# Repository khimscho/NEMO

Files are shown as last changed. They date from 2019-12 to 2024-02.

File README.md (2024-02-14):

# Low-cost Data Logger System

## Purpose

This repository contains the hardware designs, firmware source code, and supporting applications and libraries for a low-cost data logger aimed at the NMEA ([National Marine Electronics Association](https://www.nmea.org)) 0183 and 2000 protocols, as used in many marine electronics systems.  The goal is to provide a minimally-functional system to record the data appearing on NMEA0183 and NMEA2000 busses on board ships, which can be used to provide volunteer depth observations (and many other things) to assist in mapping the oceans.

## Why Have Another Logger?

There is a robust infrastructure of data loggers for both NMEA0183 and NMEA2000 busses, but they are often intended for different purposes (e.g., voyage data recorders, WiFi gateways, etc.), and they are typically order US$250 [2020] or more.  This project came out of efforts within the [Seabed 2030](https://seabed2030.gebco.net) project to map the world ocean completely by 2030, where large-scale mapping is required if the goals of the programme are to be met.  Consequently, while volunteer data is a part of the solution, it has to be something that can be scaled to very large data collections.  Since it has proven hard to sustain open data collection of this type (most of the sustained efforts have been closed, with data only going back to the collectors, and not to open databases), we believe that the only viable financial model for this purpose is to give the hardware away for free, rather than attempting to sell it for profit.  That is, the hardware is free to the data collector, who is asked just to host the hardware on their ship.  Because of this model, we need the hardware to be as low-cost as possible.

This project is therefore aimed at designing as simple, and low-cost, a logger as possible, so that as many as possible can be built and distributed to assist in mapping the oceans.  The target price is order US$30 [2020] for one interface (either NMEA0183 or NMEA2000), or US$40 [2020] for both interfaces.

At the same time, we recognise that getting data from the loggers into the national and international databases can be difficult, and ask a lot of the volunteer data collectors.  The project is therefore also attempting to define a workflow for submission of data to the [International Hydrographic Office](https://iho.int)'s [Data Center for Digital Bathymetry](https://www.ngdc.noaa.gov/iho/), hosted by the [National Centers for Environmental Information](https://www.ngdc.noaa.gov) in Boulder, CO.  The goal is to have a "Trusted Node in a Box", so that anyone wanting to support collection of data of this kind has everything they need to support a very basic data flowpath direct from the loggers through the cloud to DCDB.  (Developers are then free to add on anything else they need.)

## What Does the Logger Do?

The logger's functionality is deliberately constrained.  During normal operations, the logger monitors the NMEA0183 and/or NMEA2000 busses to which it is attached, and records any valid data packet received to local storage.  Timestamps are provided through the elapsed time counter on the microcontroller used, and although a pseudo-time is computed from NMEA2000 data packets if they are available, there is no expectation that timestamps will be assigned until the data is uploaded for processing.

The logger provides an always-on Bluetooth Low Energy service that acts as a software UART.  Client software can connect to this service and pass ASCII commands to the logger to control logging, determine the files that have been logged and their sizes, manage log files, set non-volatile parameters for the system, and so on.  Critically, the BLE service can also be used to start and stop the logger's WiFi service, which is used to give higher-speed transfer of data (although it also responds to all of the same commands).  This avoids having another WiFi network on board the ship if it is not required.

After upload to a mobile collection device (e.g., a cell-phone or tablet), the data is then sent to Amazon Web Services at the first stable communications connection of the mobile device, at which point it is processed, reformatted, packaged, and transmitted to DCDB for archive.

## Concept of Operations

This logger is designed for supported, focussed, data collections.  In this mode, loggers would be provided by an organisation in a specific geographic location to support data collection in a particular area.  The goal here is to provide density of observations in an area, which greatly assists in processing the data, and making useful products.  In addition to providing the loggers (and recruiting the volunteer observers), the organisation would also provide local support personnel to visit the volunteer observers, pick up the collected data (via mobile device), and make sure that the loggers were still collecting data.  Having local support also ensures that there is continued communication with the observers, which is useful in sustaining the community in the long term.

After each visit, all of the data collected (potentially from multiple observers) on the mobile device can be uploaded to any available service that implements the cloud segment of the software suite.  This could be something set up specifically for the organisation using the model provided here, or it could be a third-party that provides an equivalent.

## Licensing and Distribution

In order to provide for the widest possible use (and to avoid excuses ...) the hardware designs, firmware source, and supporting libraries are all released as Open Source under the MIT license.  The cloud segment is released under the MIT License for non-commercial use; for commercial licenses, please contact info@ccom.unh.edu.

## Where to Start
See the "Logger firmware" section below to get started with the WIBL loggers. 
See the "Data management" section below to get started using WIBL and 
`wibl-python` tools to manage and process data generated by WIBL loggers.

### Logger firmware

The source for the system is maintained in a [BitBucket repository](https://bitbucket.org/brian_r_calder/sb2030logger), which also includes a Wiki for details of the design and system development.

To build the system, you will need at least:

1. A functional Python interpreter (at least 3.6).

2. A working [Arduino](https://www.arduino.cc) development environment (at least 1.8.12), or equivalent (e.g., [embedXcode](https://embedxcode.weebly.com) 11.8.8).

3. Support for [Espressif](https://www.espressif.com) ESP32 development (with Arduino 1.8.12 this can be installed from the IDE, see [here](https://github.com/espressif/arduino-esp32) for instructions).

4. Support for NMEA2000 handling on ESP32 (you need the [base library](https://github.com/ttlappalainen/NMEA2000) and [ESP-specific](https://github.com/ttlappalainen/NMEA2000_esp32) extensions).

5. Eagle CAD (at least 9.5.2) for the hardware designs.

6. A working C++11 (at least) compiler for the software data simulator.

With these prerequisites, the recommended place to start is with the logger firmware, followed with the data parser Python, which will allow you to demonstrate that your logger is actually logging data.  For benchtop testing, the hardware data simulator can be used (with the development board) to generate simulated data on both NMEA0183 and NMEA2000 for testing logger modifications.  The WiFi Command GUI can be used to interact with a logger once WiFi is enabled, allowing you to transfer files, and decode them.

### Data management

The included [wibl-python](wibl-python/README.md) tools allow data from WIBL 
loggers to be processed into GeoJSON format and to be submitted to 
[DCDB](https://www.ngdc.noaa.gov/iho/). There is also a tool called 
[LogConvert](LogConvert) that allows data from TeamSurv and Yacht Devices
loggers to be converted to WIBL format for further processing using 
`wibl-python`.

An easy way to use both `wibl-python` and `LogConvert` is to use the official
WIBL [container images](DataManagement/containers/README.md).

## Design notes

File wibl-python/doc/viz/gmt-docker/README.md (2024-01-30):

# Build gmt image
```shell
docker build -t ccom-gmt:0.0.1-1 .
```

# Running gmt
```shell
docker run --rm --name gmt \
  --mount type=bind,src=./,dst=/gmt \
  -it ccom-gmt:0.0.1-1
```

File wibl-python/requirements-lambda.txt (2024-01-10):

setuptools
requests~=2.31.0
pynmea2~=1.18
csbschema~=1.1.1
# Pin to pre-urllib 2.0 to avoid this error:
#   Runtime.ImportModuleError: Unable to import module 'wibl.upload.cloud.aws.lambda_function':
#   urllib3 v2.0 only supports OpenSSL 1.1.1+, currently the 'ssl' module is compiled with
#   OpenSSL 1.0.2k-fips 26 Jan 2017. See: https://github.com/urllib3/urllib3/issues/2168
urllib3==1.26.18

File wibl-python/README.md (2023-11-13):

# Python code WIBL low-cost data logger system

## Installation

### Locally
```
pip install csbschema==1.1.1
pip install ./wibl-manager
pip install .
```

## Testing
To run unit tests, including detailed verification of packet data output by the data simulator, run:
```
pip install -r requirements-build.txt
pytest -n 4 --cov=wibl --cov-branch --cov-report=xml --junitxml=test-results.xml tests/unit/*.py
```

To run integration tests exercising much of the functionality of the `wibl` command line tool 
(except for file upload to S3 and submission DCDB):
```
bash ./tests/integration/test_wibl.bash
```

## Usage
```
]$ wibl --help
usage: wibl <command> [<arguments>]

    Commands include:
        datasim     Generate test data using Python-native data simulator.
        editwibl    Edit WIBL logger files, e.g., add platform metadata.
        uploadwibl  Upload WIBL logger files to an S3 bucket.
        parsewibl   Read and report contents of a WIBL file.
        dcdbupload  Upload a GeoJSON file to DCDB direct.

Python tools for WIBL low-cost data logger system

positional arguments:
  command     Subcommand to run

optional arguments:
  -h, --help  show this help message and exit
  --version   print version and exit

```

### Run WIBL data simulator
Run data simulator to generate test data and store it in a binary WIBL file:
```
$ wibl datasim -f test.bin -d 360 -s
```

For more information on simulator, use the `-h` option:
```
$ wibl datasim -h
usage: wibl datasim [-h] [-f FILENAME] [-d DURATION] [-s] [-b] [--use_buffer_constructor]
                    [--duplicate_depth_prob DUPLICATE_DEPTH_PROB] [-v]

Command line user interface for the NMEA data simulator.

options:
  -h, --help            show this help message and exit
  -f FILENAME, --filename FILENAME
                        Simulated data output filename
  -d DURATION, --duration DURATION
                        Duration (seconds) of the simulated data
  -s, --emit_serial     Write NMEA0183 simulated strings
  -b, --emit_binary     Write NMEA2000 simulated data packets
  --use_buffer_constructor
                        Use buffer constructor, rather than data constructor, for data packets. If not specified, data
                        constructor will be used.
  --duplicate_depth_prob DUPLICATE_DEPTH_PROB
                        Probability of generating duplicate depth values. Default: 0.0
  -v, --verbose         Produce verbose output.
```

### Edit WIBL file
Add platform metadata to existing binary WIBL file (e.g., from data simulator or from a real datalogger):
```
$ wibl editwibl -m sensor-inject.json test.bin test-inject.bin
```

### Process WIBL file into GeoJSON
Convert a binary WIBL file into GeoJSON:
```
$ wibl procwibl -c tests/fixtures/configure.local.json test-inject.bin test-inject.geojson
```

> Note: It is necessary to supply a configuration JSON file with the `local` attribute
> set to `true`, such as `tests/fixtures/configure.local.json`, because `procwibl` uses
> the same code as the conversion processing lambda code run in the cloud.

### Upload WIBL files into AWS S3 Buckets for processing
Instead of using the mobile app (and for testing), WIBL binary files can be uploaded into a given S3 bucket to trigger processing.  If the file is being uploaded into the staging bucket (i.e., to test transfer to DCDB), a '.json' extension must be added (``-j|--json``), and the SourceID tag must be set (``-s|--source``) so that the submission Lambda can find this information.
```
$ wibl uploadwibl -h
usage: wibl uploadwibl [-h] [-b BUCKET] [-j] [-s SOURCE] input

Upload WIBL logger files to an S3 bucket (in a limited capacity)

positional arguments:
  input                 WIBL format input file

options:
  -h, --help            show this help message and exit
  -b BUCKET, --bucket BUCKET
                        Set the upload bucket name (string)
  -j, --json            Add .json extension to UUID for upload key
  -s SOURCE, --source SOURCE
                        Set SourceID tag for the S3 object (string)
```

### Parse WIBL binary files
Raw WIBL binary files can be read and transcribed in ASCII format for debug.  Statistics on which NMEA2000 talkers, and which packets, are observed can be dumped at the end of the read (``-s|--stats``).
```
$ wibl parsewibl -h
usage: wibl parsewibl [-h] [-s] input

Parse WIBL logger files locally and report contents.

positional arguments:
  input        Specify the file to parse

options:
  -h, --help   show this help message and exit
  -s, --stats  Provide summary statistics on packets seen
```

### Uploading GeoJSON files to DCDB directly
Instead of using the cloud-based submission process (and for debugging), pre-formatted GeoJSON files can be uploaded directly to DCDB for archival.  Note that the file containing the provider authorisation token (provided by DCDB for each Trusted Node) has to be set on the command line (``-a|--auth``), although the rest of the information (provider ID, upload point) can be specified through the JSON configuration file (``-c|--config``); the provider ID (specified by DCDB for each Trusted Node) can be over-ridden on the command line (``-p|--provider``).  The source ID is read from the GeoJSON file, unless it is set on the command line (``-s|--source``).

```
wibl dcdbupload -h
usage: wibl dcdbupload [-h] [-s SOURCEID] [-p PROVIDER] [-a AUTH] [-c CONFIG] input

Upload GeoJSON files to DCDB for archival.

positional arguments:
  input                 GeoJSON file to upload to DCDB

optional arguments:
  -h, --help            show this help message and exit
  -s SOURCEID, --sourceid SOURCEID
                        Set SourceID as in the GeoJSON metadata.
  -p PROVIDER, --provider PROVIDER
                        Provider ID as generated by DCDB
  -a AUTH, --auth AUTH  File containing the Provider authorisation token generated by DCDB
  -c CONFIG, --config CONFIG
                        Specify configuration file for installation
```

Configuration files suitable for uploading to both the test and production DCDB endpoints are available in the
[examples](examples) directory; For test uploads, use [configure-submission-test.json](examples/configure-submission-test.json),
and for production uploads use [configure-submission.json](examples/configure-submission.json).

## Packaging and Deploying Processing and Submission Code
Packaging up the software for the cloud segment, and deploying it, can be a little involved due to security concerns with the various cloud providers.  Detailed setup instructions, and automation scripts, are provided as described below.

### AWS
There are a number of steps required to set up the AWS Lambdas, the S3 buckets, and associated triggers and permissions in order to make processing work in the cloud.  The steps are covered in detail in the [Setup Instructions](scripts/cloud/AWS/README.md), and a corresponding set of scripts are available in the [scripts](scripts/cloud/AWS) directory in the repository.  These scripts should *mostly* work, but will likely need some modification for a local configuration before being fully executable.  Consider the `configuration-parameters.sh` file first for this.

## Configuration for Local Use
The ``wibl`` tool can be installed locally as above, but needs a configuration JSON file for some of the sub-commands (e.g., to send data to DCDB) rather than using environment variables as with the cloud-based processing.  Scripts in `wibl-python/scripts/desktop` will generate the `configure/json` required (configure `configuration-parameters.sh` and then run `configure-desktop.sh`).

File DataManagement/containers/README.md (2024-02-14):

# Base container images for running WIBL in Docker
This page describes how to use WIBL base container imagers for running WIBL
in Docker or other container runtime environments.

There are currently two tags for the WIBL container image: `1.0.3-amazonlinux`
and `1.0.3`, which at present reference the same image. For more information
see [here](https://github.com/CCOMJHC/WIBL/pkgs/container/wibl). In the 
future these may be separated into distinct images for those not using
Amazon Linux.

The WIBL container image contains installed and runnable versions of both 
[wibl-python](../../wibl-python/README.md) and [LogConvert](../../LogConvert). 
For more information about how these tools and setup and installed, see
the [Dockerfile](cloud/AWS/Dockerfile).

To see how the WIBL container image was built, see [BUILDING.md](BUILDING.md).

## Use directly using `docker run`
To run a `wibl-python` command within the container while reading and
writing data from a directory on your host computer, do the following:
```shell
$ docker run -v ./:/var/wibl -ti ghcr.io/ccomjhc/wibl:1.0.3 'wibl datasim -f test.bin -d 360 -b'
...
INFO:wibl.command.datasim:Step to time: 359000000
INFO:wibl.command.datasim:Step to time: 359157800
INFO:wibl.command.datasim:Step to time: 360000000
INFO:wibl.command.datasim:Total iterations: 600
$ docker run -v ./:/var/wibl -ti ghcr.io/ccomjhc/wibl:1.0.3 'wibl editwibl -m sensor-inject.json test.bin test-inject.bin'
...
```

where:
 - `-v ./:/var/wibl` mounts the current working directory from the host to `/var/wibl` in the container.
 - `'wibl datasim -f test.bin -d 360 -b'` is the `wibl-python` command to run in the container

> Note: the entire command to be run in the container must be enclosed in quotes

Since it can be error-prone to specify the full `docker run` command each
time you run a `wibl-python` command, it can be easier to open a shell
in the `wibl-base` container, then run multiple `wibl` commands:
```shell
$ docker run -v ./:/var/wibl -ti ghcr.io/ccomjhc/wibl:1.0.3
bash-5.2# wibl datasim -f test.bin -d 360 -b
...
INFO:wibl.command.datasim:Step to time: 359000000
INFO:wibl.command.datasim:Step to time: 359467302
INFO:wibl.command.datasim:Step to time: 360000000
INFO:wibl.command.datasim:Total iterations: 603
bash-5.2# wibl editwibl -m sensor-inject.json test.bin test-inject.bin 
...
bash-5.2# exit
exit
```

## Use in your own `Dockerfile`
To build your own image based off of the WIBL image, make a `Dockerfile` that
begins with the following:
```Dockerfile
FROM ghcr.io/ccomjhc/wibl:1.0.3
...
```

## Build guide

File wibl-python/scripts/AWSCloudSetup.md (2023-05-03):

# Packaging and deploying AWS lambdas for DCDB processing
There are a number of steps required to set up the AWS Lambdas, the S3 buckets, and associated triggers and permissions in order to make processing work in the cloud.  The steps are covered in detail below, and a corresponding set of scripts are available in the `wibl-python/AWS-setup` directory in the repository.  These scripts should *mostly* work, but will likely need some modficiation for a local configuration before being fully executable.  Consider the `configuration-parameters.sh` file first for this.

## Creating S3 Buckets
The cloud processing segment uses two AWS S3 buckets to receive the incoming data (`INCOMING_BUCKET`) and to stage processed data (`STAGING_BUCKET`) for further analysis, or before they're sent to DCDB for archive.  Creating these from the CLI is relatively straightforward:

```bash
aws s3api create-bucket \
    --bucket INCOMING_BUCKET \
    --region REGION \
    --create-bucket-configuration LocationConstraint=REGION
aws s3api create-bucket \
    --bucket STAGING_BUCKET \
    --region REGION \
    --create-bucket-configuration LocationConstraint=REGION
```

where `INCOMING_BUCKET` and `STAGING_BUCKET` are the short names for the buckets (i.e., not the full ARN), and `REGION` is the AWS region.  Since S3 buckets are global objects, you do not need to specifically set the `REGION`, but doing so can be advantageous since the data will stay within the same facility as the Lambdas, which can improve performance.  If you do not specify the region, us-east-1 (Virginia) is used.  Specifying the `create-bucket-configuration` is only required if you do specify the `REGION`.

## Create IAM roles for WIBL lambdas
First, create an IAM role for each lambda (e.g., processing and submission). We'll do this using the AWS CLI rather
than the AWS web console since this enables us to automate lambda configuration. Also, the CLI tends to change less
often than the web console user interface, so these instructions should last much longer without updating.

First create the following trust policy JSON file:
```bash
$ cat > trust-policy.json <<-HERE
{
 "Version": "2012-10-17",
  "Statement": [
    {
      "Effect": "Allow",
      "Principal": {
        "Service": ["lambda.amazonaws.com"]
      },
      "Action": "sts:AssumeRole"
    }
  ]
}
HERE
```
Then create the IAM role for the processing lambda:
```bash
$ aws iam create-role \
  --role-name wibl-processing-lambda \
  --assume-role-policy-document file://trust-policy.json
```

Next, create the IAM role for the submission lambda:
```bash
$ aws iam create-role \
  --role-name wibl-submission-lambda \
  --assume-role-policy-document file://trust-policy.json
```

> Make a copy of the role ARNs returned to you after running these commands. We'll need them to create the lambdas below.

Attach the following policy to allow Lambda to write logs in CloudWatch, processing lambda:
```bash
$ aws iam attach-role-policy \
  --role-name wibl-processing-lambda \
  --policy-arn arn:aws:iam::aws:policy/service-role/AWSLambdaBasicExecutionRole
```

also for submission lambda:
```bash
$ aws iam attach-role-policy \
  --role-name wibl-submission-lambda \
  --policy-arn arn:aws:iam::aws:policy/service-role/AWSLambdaBasicExecutionRole
```

> Note: it takes a little while for the roles to propagate out to the rest of the AWS infrastructure, so if you
> attempt to use the roles to create Lambdas before they've finished, you'll get odd errors.  Something on the
> order to 5-10 s appears to work, but this could vary depending on the region that you're in.

## Package lambdas as zipfile
> Note: the following is based on [AWS lambda deployment instructions](https://docs.aws.amazon.com/lambda/latest/dg/python-package.html#python-package-create-package-with-dependency)

Since all WIBL AWS lambdas are part of the same Python package called `wibl`, we'll only need to create a single
package. We can specify different lambda handler functions when creating the individual lambdas below.

First (and optionally), run a shell within the Amazon Linux Python 3.8 lambda runtime:
```
$ docker run \
  --mount type=bind,source="$(pwd)/.",target=/build \
  -it --entrypoint /bin/bash \
  public.ecr.aws/lambda/python:3.8-x86_64
```

The reason you might want to package lambdas within Amazon Linux Python 3.8 lambda runtime is that it should be nearly
identical to the environment where the lambda will run. This way, you can reduce the risk of introducing any platform-
or architecture-specific dependencies. That said, since we are using AWS layers to configure some of the dependencies
for our lambdas (e.g., including platform- and architecture-specific dependencies such as numpy), and since the
dependencies we *are* bundlying in our lambda zipfile (as specified by
[requirements-lambda.txt](requirements-lambda.txt)) *should* be pure Python, it *should* be okay to create this
package on either non-Amazon versions of Linux, or under recent versions of macOS. However, it is probably a good idea
to use Amazon Linux Python 3.8 lambda runtime to package these lambdas.

> It should be possible to use the ARM64 architecture to package and deploy the Lambdas, but there are limitations
> to the support facilities in the currently available Lambda runtimes, particularly with respect to Python versions
> and SciPy installed versions.  This can cause the Lambda to abort before booting when triggered.

> Similarly, it should be possible to use more recent Python runtimes, but they often don't have good support for the
> SciPy layer that's required for the WIBL code.  This may change over time; the WIBL code is typically tested with
> the most recent version of Python.

Second, install WIBL and its dependencies into a target directory called `package` located in the current directory:
```
$ cd /build
$ pip install --target ./package -r requirements-lambda.txt
$ pip install --target ./package ./wibl-manager
$ pip install --target ./package --no-deps .
```

> Note: if building in Amazon Linux Python 3.8 lambda runtime, make sure to run these in the shell you started in
> Docker above rather than in a shell on your host OS.  You can do this by hand, or by sending the commands into a file, and then piping it into the docker command (remove the ``-t`` option if you do this).

> Note: we break out the install into two steps so that we package *only* the subset of `wibl` dependencies that will
> not be provided by AWS lambda layers used when we create the lambda below.

Next, make a zipfile of the `package` directory:
```
$ pushd .
$ cd package
$ zip -r ../wibl-package.zip .
$ popd
```

> Note: if building in Amazon Linux Python 3.8 lambda runtime, you'll have to run this from your host since `zip` is not
> installed by default.

## Create the processing lambda
```
$ aws lambda create-function \
  --function-name wibl-processing \
  --role arn:aws:iam::ACCOUNT_NUMBER:role/wibl-processing-lambda \
  --runtime python3.8 --timeout 30 --memory-size 2048 \
  --handler wibl.processing.cloud.aws.lambda_function.lambda_handler \
  --zip-file fileb://wibl-package.zip \
  --architectures x86_64 \
  --layers LAYER1 ... LAYERN \
  --environment "Variables={PROVIDER_ID=MY_PROVIDER_ID,STAGING_BUCKET=MY_STAGING_BUCKET,UPLOAD_POINT=https://www.ngdc.noaa.gov/ingest-external/upload/csb/geojson/}"
```

where `ACCOUNT_NUMBER` is your AWS account number, and where `LAYER1 ... LAYERN` are replaced by the names of the AWS lambda layers we would like to deploy this lambda on top of (to avoid repackaging dependencies).  See the example configuration file for definitions of the environment variables.

> Note: by default, the lambda will use the configuration file installed as part of the `wibl` Python package. You can
> find this default file in [here](wibl/defaults/processing/cloud/aws/configure.json). If you want to use another file,
> make sure to add it to the `package` directory created above and set an environment variable named `WIBL_CONFIG_FILE`
> (value is the path within the package to the desired configuration file) when creating the lambda function.

> Note: if you want to use ARM64 instead of x86_64 architecture, change `--architectures x86_64` to
> `--architectures arm64`.

> The `timeout` and `memory-size` settings may have to be adjusted for your implementation; these defaults work
> reasonably for the default code-base.

> Note: the layer name is the full ARN for the layer required.  You will need at least the SciPy layer for a
> default build of the code; this is likely
> arn:aws:lambda:us-east-2:259788987135:layer:AWSLambda-Python38-SciPy1x:107 (or the equivalent for your AWS region).

## Configure the Processing Lambda to Trigger from S3
To have the processing lambda triggered by the upload of a file into an S3 bucket, you need to configure the lambda to be triggerable, configure the bucket to generate notifications (and send them to the lambda), and then configure the lambda to allow for access to the S3 bucket.  In order:

```
$ aws lambda add-permission \
  --function-name wibl-processing \
  --action lambda:InvokeFunction \
  --statement-id s3invoke \
  --principal s3.amazonaws.com \
  --source-arn arn:aws:s3:::INCOMING_BUCKET \
  --source-account ACCOUNT_NUMBER
```
where `INCOMING_BUCKET` is the name of the S3 bucket that you'll upload data into from the outside world, and `ACCOUNT_NUMBER` is the AWS account number for your installation.

> Note: Some services can invoke functions in other accounts. If you specify a source
> ARN that has your account ID in it, that isn't an issue. For Amazon S3, however, the
> source is a bucket whose ARN doesn't have an account ID in it. It's possible that you
> could delete the bucket and another account could create a bucket with the same name.
> Using the source-account option with your account ID ensures that only resources in
> your account can invoke the function.

> Note: Once the permissions are added to the Lambda, there's a propagation time for the Lambda to complete
> setup, and then propagate this out to the rest of the AWS infrastructure.  If you attempt to target the
> Lambda (e.g., to do the next stage of adding the trigger) without waiting for this to happen, odd errors
> occur.  A delay of 5-10 s seems to be appropriate, but may depend on the region that you're in.

Generate a configuration file for the bucket to notify the lambda:
```bash
$ cat > bucket-notification-cfg.json <<-HERE
{
    "LambdaFunctionConfigurations": [
        {
            "Id": "IDENTIFIER",
            "LambdaFunctionArn": "arn:aws:lambda:REGION:ACCOUNT_NUMBER:function:wibl-processing",
            "Events": [
                "s3:ObjectCreated:Put",
                "s3:ObjectCreated:CompleteMultipartUpload"
            ]
        }
    ]
}
HERE
```
where `IDENTIFIER` is a unique identifier (e.g., a UUID), `REGION` is your AWS region, and `ACCOUNT_NUMBER` is as above.  You can obtain the ARN for your bucket directly from the AWS console if necessary.  Then apply the notification to the bucket:

```bash
$ aws s3api put-bucket-notification-configuration \
  --bucket INCOMING_BUCKET \
  --notification-configuration file://bucket-notification-cfg.json
```
where `INCOMING_BUCKET` is the short form name of the bucket you're using for incoming files, as above.

Finally, generate a configuration file to allow the lambda access to the S3 bucket:
```bash
$ cat > lambda-s3-access.json <<-HERE
{
    "Version": "2012-10-17",
    "Statement": [
        {
            "Sid": "LambdaAllowS3Access",
            "Effect": "Allow",
            "Action": [
                "s3:*"
            ],
            "Resource": [
                "arn:aws:s3:::INCOMING_BUCKET",
                "arn:aws:s3:::INCOMING_BUCKET/*",
                "arn:aws:s3:::STAGING_BUCKET",
                "arn:aws:s3:::STAGING_BUCKET/*"
            ]
        }
    ]
}
HERE
```
and apply it to the lambda:
```bash
$ aws iam put-role-policy \
  --role-name wibl-processing-lambda \
  --policy-name lambda-s3-access \
  --policy-document file://lambda-s3-access.json
```
and then convince yourself that it has been applied:
```bash
$ aws iam list-role-policies --role-name wibl-processing-lambda
```
which should report something like:
```
{
    "PolicyNames": [
        "lambda-s3-access"
    ]
}
```

At this stage, submitting a WIBL file to the `INCOMING_BUCKET` should result in the file being processed and written into the `STAGING_BUCKET` that was specified in the environment variables of the WIBL package.

## Create the submission lambda
```bash
$ aws lambda create-function \
  --function-name wibl-submission \
  --role arn:aws:iam::ACCOUNT_NUMBER:role/wibl-submission-lambda \
  --runtime python3.8 --timeout 30 --memory-size 2048 \
  --handler wibl.submission.cloud.aws.lambda_function.lambda_handler \
  --zip-file fileb://wibl-package.zip \
  --architectures x86_64 \
  --environment "Variables={PROVIDER_ID=MY_PROVIDER_ID,PROVIDER_AUTH=MY_PROVIDER_AUTH_KEY,STAGING_BUCKET=MY_STAGING_BUCKET,UPLOAD_POINT=https://www.ngdc.noaa.gov/ingest-external/upload/csb/geojson/}"
```

> Note: the submission lambda takes an additional environment variable `PROVIDER_AUTH`, which is an authentication key
> used for making submissions to the HTTP service denoted by `UPLOAD_POINT`.

> Note: by default, the lambda will use the configuration file installed as part of the `wibl` Python package. You can
> find this default file in [here](wibl/defaults/submission/cloud/aws/configure.json). If you want to use another file,
> make sure to add it to the `package` directory created above and set an environment variable named `WIBL_CONFIG_FILE`
> (value is the path within the package to the desired configuration file) when creating the lambda function.

## Configure the Submission Lambda to Automatically Trigger
The process for this is essentially the same as for the processing Lambda, with some obvious modifications to match the particular buckets in use.

First, create a bucket notification so that files being added to the STAGING_BUCKET by the processing Lambda trigger the submission Lambda:
```bash
cat >bucket-notification-cfg.json <<-HERE
{
    "LambdaFunctionConfigurations": [
        {
            "Id": "${UUID}",
            "LambdaFunctionArn": "arn:aws:lambda:REGION:ACCOUNT_NUMBER:function:wibl-submission",
            "Events": [
                "s3:ObjectCreated:Put",
                "s3:ObjectCreated:CompleteMultipartUpload"
            ]
        }
    ]
}
HERE
```

and then apply it to the STAGING_BUCKET as before:
```bash
aws s3api put-bucket-notification-configuration \
	--bucket STAGING_BUCKET \
	--notification-configuration file://bucket-notification-cfg.json
```

Next, generate an access policy to allow the submission Lambda to access the STAGING_BUCKET:
```bash
cat >lambda-s3-access.json <<-HERE
{
    "Version": "2012-10-17",
    "Statement": [
        {
            "Sid": "LambdaAllowS3Access",
            "Effect": "Allow",
            "Action": [
                "s3:*"
            ],
            "Resource": [
                "arn:aws:s3:::STAGING_BUCKET",
                "arn:aws:s3:::STAGING_BUCKET/*"
            ]
        }
    ]
}
HERE
```

and then add the permissions on the submission Lambda to allow it to be invoked by S3,
```bash
aws lambda add-permission \
  --function-name wibl-submission \
	--action lambda:InvokeFunction \
	--statement-id s3invoke \
	--principal s3.amazonaws.com \
	--source-arn arn:aws:s3:::STAGING_BUCKET \
	--source-account ACCOUNT_NUMBER
```

and then add the policy for permissions,
```bash
aws iam put-role-policy \
	--role-name wibl-submission-lambda \
	--policy-name lambda-s3-access \
	--policy-document file://lambda-s3-access.json
```

> Note: The same delays between Lambda creation and adding the trigger as for the processing Lambda are required.

# Upload a New Version of a Lambda
```bash
$ aws lambda update-function-code --function-name wibl-processing \
  --zip-file fileb://wibl-package.zip
```

# Change Lambda Environment
```bash
$ aws lambda update-function-configuration \
  --function-name wibl-submission \
  --environment "Variables={PROVIDER_ID=MY_PROVIDER_ID_UPDATED,PROVIDER_AUTH=MY_PROVIDER_AUTH_KEY_UPDATED,STAGING_BUCKET=MY_STAGING_BUCKET_UPDATED,UPLOAD_POINT=https://www.ngdc.noaa.gov/ingest-external/upload/csb/geojson/}"
```

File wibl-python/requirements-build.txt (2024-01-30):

setuptools
boto3~=1.20
requests~=2.31.0
numpy~=1.20
pynmea2~=1.18
csbschema~=1.1.1
pygmt~=0.10.0
rasterio~=1.3.0
GDAL
pylint~=3.0.0
unittest-xml-reporting==3.2.0
lxml~=5.0.0
pytest~=7.4.0
pytest-cov
pytest-xdist
pytest-docker[docker-compose-v2]

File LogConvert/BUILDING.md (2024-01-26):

# Instructions for building LogConvert

## Amazon Linux 2023
Use the provided [Dockerfile](Dockerfile) as a starting point for building and running LogConvert
in Amazon Linux 2023 environments (e.g., public.ecr.aws/lambda/python:3.12).

### AMD64
```shell
$ docker buildx build --platform linux/amd64 -t wibl/logconvert:latest ./
```

### ARM64
```shell
$ docker buildx build --platform linux/arm64 -t wibl/logconvert:latest ./
```

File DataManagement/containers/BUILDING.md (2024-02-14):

# Base container images for running WIBL in Docker
This page describes how to build WIBL base container imagers for running WIBL
in Docker or other container runtime environments. The following steps
assum you are using [Docker Desktop](https://www.docker.com/products/docker-desktop/).

## Build
To build, do the following:
```shell
$ docker buildx build \
  --platform linux/amd64,linux/arm64 --builder=desktop-linux \
  -t ghcr.io/ccomjhc/wibl:1.0.3-amazonlinux -t ghcr.io/ccomjhc/wibl:1.0.3 \
  cloud/AWS
```

> Note: If you don't have a builder named `desktop-linux`, run `docker buildx ls`
> to find the name of your builder.

> Note: For now, we tag this image both as `1.0.3-amazonlinux` and 
> `1.0.3`. In the future we may plan to build a version of the that is
> not based on Amazon Linux.

To push, first store your GitHub container registry personal access token to
an environment variable named `CR_PAT`, then login:
```shell
$ echo $CR_PAT | docker login ghcr.io -u USERNAME --password-stdin
```

> For more info on pushing images, see [here](https://docs.github.com/en/packages/working-with-a-github-packages-registry/working-with-the-container-registry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)

Then push:
```shell
$ docker image push --all-tags ghcr.io/ccomjhc/wibl
```

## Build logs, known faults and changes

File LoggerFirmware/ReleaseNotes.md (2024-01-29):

# Release Notes: Logger Firmware

## Firmware 1.5.0

Firmware 1.5.0 includes the following additions:

* __Internal website__.  The logger can now host its own configuration and manipulation software, providing these to any browser as a mixture of HTML/CSS/JavaScript.  Data download is through normal browser download mechanisms by exposing the log files as a static website and providing download links as part of the website status page.  This makes the logger self-hosting.
* __Data Integrity__.  Monitoring for the latest time/position/depth on NMEA0183 and NMEA2000 inputs so that the status page on the internal website can demonstrate whether the logger is receiving data (ideal for installation, but also good for debugging while underway).
* __Auto-upload__.  If the logger is connected to a network that has internet connection, it can now be configured to automatically connect to a server to upload log files, using TLS for the connection and HTTP BasicAuth for authentication.  The upload events happen at a fixed interval, and run for a fixed duration (or until all of the files are transferred) so that the code doesn't dominate the logger's functionality while uploading.  A separate timeout parameter ensures the system doesn't halt if the server isn't available.
* __Data Monitoring__.  Ability to include algorithm requests dynamically based on the data being captured.  This resolves the issue to "no data" values in NMEA2000 inputs causing chaos in post.
* JSON output for all commands when using the WiFi interface.  This includes error messages as a JSON response with just a "messages" tag and an array of strings.
* A consistently reported firmware version in configuration and status information.
* Addition of NVM storage for an upload token (e.g., for an API key).
* "/heartbeat" API endpoint on the logger's WiFi interface now generates a full status message, rather than just the serial number of the logger.
* Console logs are now limited to a fixed (compile-time) size, but will rotate three stages (grandparent-parent-child) to preserve a little more history.
* Scales, metadata, NMEA0183 filters, and algorithm requests are now all stored as JSON data int the NVM, rather than as plain-text files.
* The status command now provides the URL at which to find each log file, as well as size, MD5 hash, ID number, and upload count.
* New command "snapshot" to generate a snapshot of the running configuration, default configuration, or file catalog as files on the SD card so that they can be downloaded to local storage on a mobile device.  The JSON response is the URL at which to find the snapshot.  The internal website implements this functionality through GUI buttons.
* New command "upload" to control auto-upload of log files.
* New command "auth" to control auto-upload authentication artifacts.
* Ability to specify more than one NMEA0183 sentence recognition string in "accept" command in a single command.

Note that this release also updates the command processor version to 1.4.0.

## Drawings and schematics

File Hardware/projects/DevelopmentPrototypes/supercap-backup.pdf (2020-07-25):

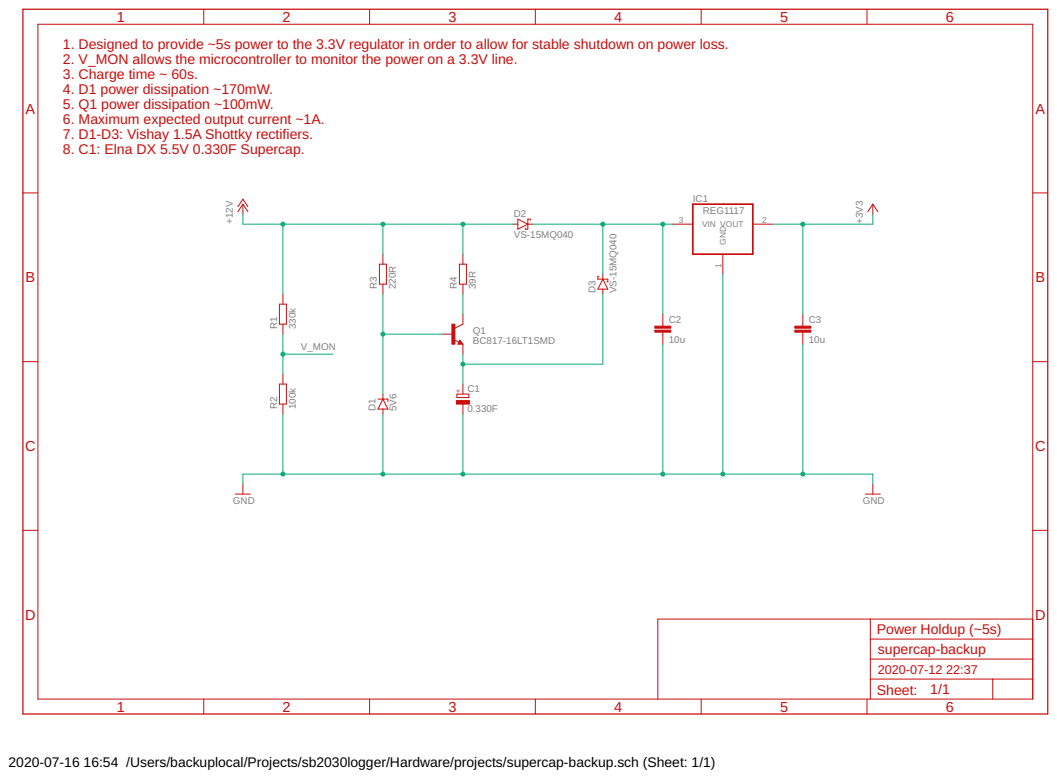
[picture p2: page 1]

1. Designed to provide ~5s power to the 3.3V regulator in order to allow for stable shutdown on power loss. 2. V_MON allows the microcontroller to monitor the power on a 3.3V line. 3. Charge time ~ 60s. 4. D1 power dissipation ~170mW. 5. Q1 power dissipation ~100mW. 6. Maximum expected output current ~1A. 7. D1-D3: Vishay 1.5A Shottky rectifiers. 8. C1: Elna DX 5.5V 0.330F Supercap.

2020-07-16 16:54 /Users/backuplocal/Projects/sb2030logger/Hardware/projects/supercap-backup.sch (Sheet: 1/1)

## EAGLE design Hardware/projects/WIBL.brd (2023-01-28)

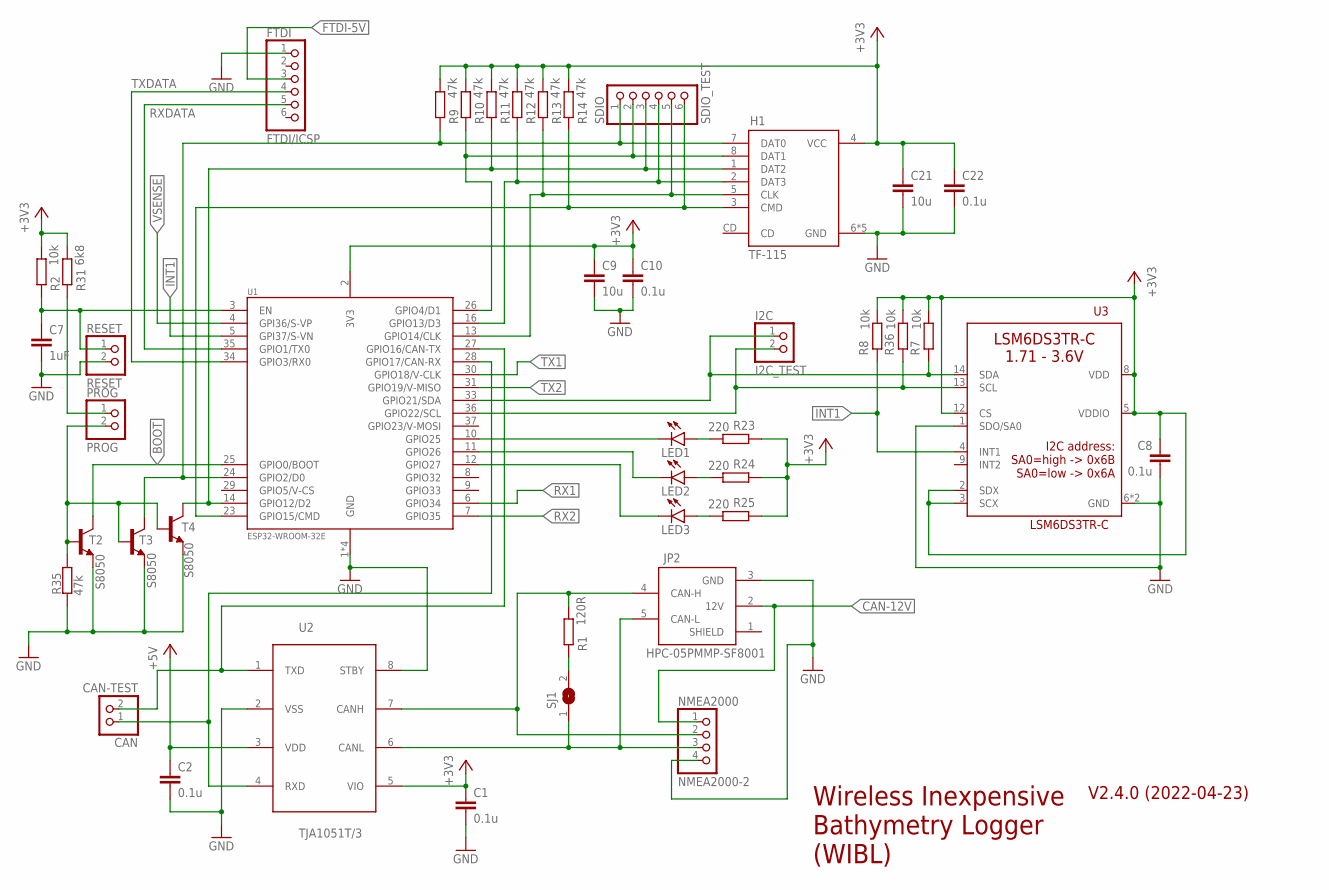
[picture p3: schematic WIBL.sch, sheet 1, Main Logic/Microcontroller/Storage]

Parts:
C1, C2, C8, C10, C22: 0.1u; C0805
C7: 1uF; C0805
C9, C21: 10u; C0805
CAN: CAN-TEST; 1X02
FTDI: FTDI/ICSP; 1X06
H1: TF-115; XUNPU-MICROSD-SOCKET
I2C: I2C_TEST; 1X02
JP2: HPC-05PMMP-SF8001; NMEA2000
LED1, LED2, LED3: LEDCHIP-LED0603; CHIP-LED0603
NMEA2000: NMEA2000-2; 1X04
PROG: PROG; 1X02
R1: 120R; R0805
R2, R7, R8, R36: 10k; R0805
R9, R10, R11, R12, R13, R14, R35: 47k; R0805
R23, R24, R25: 220; R0805
R31: 6k8; R0805
RESET: RESET; 1X02
SDIO: SDIO_TEST; 1X06
SJ1: SJ
T2, T3, T4: S8050; SOT23
U1: ESP32-WROOM-32E; ESPS32-WROOM-32E
U2: TJA1051T/3; SOIC8
U3: LSM6DS3TR-C; LGA-14-2.5X3MM

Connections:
+3V3: C1.1, C8.1, C9.1, C10.1, C21.1, C22.1, H1.4 (VCC), R2.2, R7.2, R8.2, R9.2, R10.2, R11.2, R12.2, R13.2, R14.2, R23.1, R24.1, R25.1, R31.2, R36.2, U1.2 (3V3), U2.5 (VIO), U3.2 (SDX), U3.3 (SCX), U3.5 (VDDIO), U3.8 (VDD), U3.12 (CS); also elsewhere on the board
+5V: C2.1, U2.3 (VDD); also elsewhere on the board
BOOT: T2.3 (C), U1.25 (GPIO0/BOOT); also elsewhere on the board
CAN-12V: JP2.2 (12V), NMEA2000.1; also elsewhere on the board
FTDI-5V: FTDI.3; also elsewhere on the board
GND: C1.2, C2.2, C7.2, C8.2, C9.2, C10.2, C21.2, C22.2, FTDI.1, H1.6 (GND), H1.GND1 (GND), H1.GND2 (GND), H1.GND3 (GND), H1.GND4 (GND), JP2.3 (GND), NMEA2000.4, R35.1, RESET.2, T2.2 (E), T3.2 (E), T4.2 (E), U1.1 (GND), U1.15 (GND), U1.38 (GND), U1.THERM (GND), U2.2 (VSS), U2.8 (STBY), U3.1 (SDO/SA0), U3.6 (GND), U3.7 (GND); also elsewhere on the board
INT1: R8.1, U1.5 (GPI37/S-VN), U3.4 (INT1)
unnamed: JP2.4 (CAN-H), NMEA2000.2, R1.2, U2.7 (CANH)
unnamed: JP2.5 (CAN-L), NMEA2000.3, SJ1.1, U2.6 (CANL)
unnamed: R1.1, SJ1.2
unnamed: C7.1, R2.1, RESET.1, U1.3 (EN)
unnamed: CAN.2, U1.27 (GPIO16/CAN-TX), U2.1 (TXD)
unnamed: CAN.1, U1.28 (GPIO17/CAN-RX), U2.4 (RXD)
unnamed: H1.1 (DAT2), R11.1, SDIO.3, T4.3 (C), U1.14 (GPIO12/D2)
unnamed: H1.8 (DAT1), R10.1, SDIO.2, U1.26 (GPIO4/D1)
unnamed: H1.7 (DAT0), R9.1, SDIO.1, T3.3 (C), U1.24 (GPIO2/D0)
unnamed: H1.2 (DAT3), R12.1, SDIO.4, U1.16 (GPIO13/D3)
unnamed: H1.5 (CLK), R13.1, SDIO.5, U1.13 (GPIO14/CLK)
unnamed: H1.3 (CMD), R14.1, SDIO.6, U1.23 (GPIO15/CMD)
unnamed: LED1.C, U1.10 (GPIO25)
unnamed: LED2.C, U1.11 (GPIO26)
unnamed: PROG.2, R35.2, T2.1 (B), T3.1 (B), T4.1 (B)
unnamed: LED3.C, U1.12 (GPIO27)
unnamed: LED1.A, R23.2
unnamed: LED2.A, R24.2
unnamed: PROG.1, R31.1
unnamed: LED3.A, R25.2
RX1: U1.6 (GPIO34); also elsewhere on the board
RX2: U1.7 (GPIO35); also elsewhere on the board
RXDATA: FTDI.5, U1.35 (GPIO1/TX0)
SCL: I2C.1, R7.1, U1.33 (GPIO21/SDA), U3.14 (SDA)
SDA: I2C.2, R36.1, U1.36 (GPIO22/SCL), U3.13 (SCL)
TX1: U1.30 (GPIO18/V-CLK); also elsewhere on the board
TX2: U1.31 (GPIO19/V-MISO); also elsewhere on the board
TXDATA: FTDI.4, U1.34 (GPIO3/RX0)
VSENSE: U1.4 (GPI36/S-VP); also elsewhere on the board

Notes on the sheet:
Wireless Inexpensive Bathymetry Logger (WIBL)
V2.4.0 (2022-04-23)

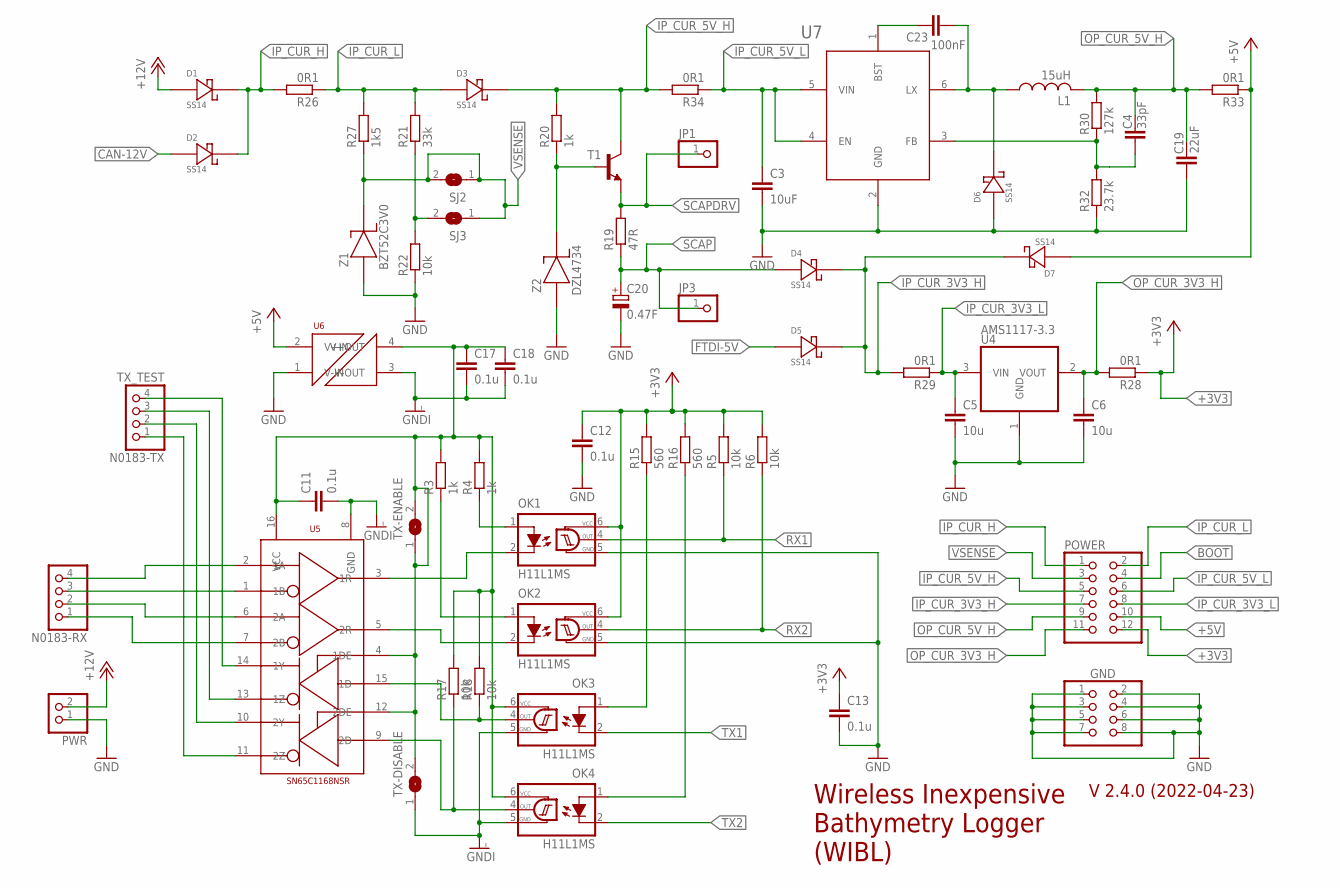
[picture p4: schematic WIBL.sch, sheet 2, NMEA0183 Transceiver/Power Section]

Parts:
C3: 10uF; C1206
C4: 33pF; C0603
C5, C6: 10u; C0805
C11, C12, C13, C17, C18: 0.1u; C0805
C19: 22uF; C0603
C20: 0.47F; P128-50
C23: 100nF; C0402
D1, D2, D3, D4, D5, D6, D7: SS14; DO-214AC
GND: PINHD-2X4; 2X04
JP1, JP3: PINHD-1X1; 1X01
L1: 15uH; MWSA0603S
N0183-RX: PINHD-1X4; 1X04
N0183-TX: TX_TEST; 1X04
OK1, OK2, OK3, OK4: H11L1MS; DIL6-SMD
POWER: PINHD-2X6; 2X06
PWR: PINHD-1X2; 1X02
R3, R4, R20: 1k; R0805
R5, R6, R17, R18, R22: 10k; R0805
R15, R16: 560; R0805
R19: 47R; R0805
R21: 33k; R0805
R26, R28, R29, R33, R34: 0R1; R0603
R27: 1k5; R0805
R30: 127k; R0603
R32: 23.7k; R0603
SJ2, SJ3: SJ
T1: BC817-16-NPN-SOT23-BEC; SOT23-BEC
TX-DISABLE: SJ
TX-ENABLE: SJ
U4: AMS1117-3.3; SOT223
U5: SN65C1168NSR; SOIC16
U6: RFM-0505S
U7: BL9352A; SOT-23-6L
Z1: BZT52C3V0; SOD123
Z2: DZL4734; SOD-123FL

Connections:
+3V3: C12.1, C13.1, OK1.6 (VCC), OK2.6 (VCC), POWER.12, R5.2, R6.2, R15.2, R16.2, R28.1; also elsewhere on the board
+5V: D7.A, POWER.10, R33.1, U6.2 (V+IN); also elsewhere on the board
+12V: D1.A, PWR.2
BOOT: POWER.4; also elsewhere on the board
CAN-12V: D2.A; also elsewhere on the board
FTDI-5V: D5.A; also elsewhere on the board
GND: C3.2, C5.2, C6.2, C12.2, C13.2, C19.1, C20.-, D6.A, GND.1, GND.2, GND.3, GND.4, GND.5, GND.6, GND.7, GND.8, OK1.5 (GND), OK2.5 (GND), PWR.1, R22.1, R32.1, U4.1 (GND), U6.1 (V-IN), U7.2 (GND), Z1.1 (A), Z2.A; also elsewhere on the board
GNDI: C11.2, C17.2, C18.2, OK3.5 (GND), OK4.5 (GND), TX-DISABLE.1, U5.8 (GND), U6.3 (V-OUT)
IP_CUR_3V3_H: D4.K, D5.K, D7.K, POWER.7, R29.2
IP_CUR_3V3_L: C5.1, POWER.8, R29.1, U4.3 (VIN)
IP_CUR_5V_H: D3.K, POWER.5, R20.2, R34.2, T1.C
IP_CUR_5V_L: C3.1, POWER.6, R34.1, U7.4 (EN), U7.5 (VIN)
IP_CUR_H: D1.K, D2.K, POWER.1, R26.2
IP_CUR_L: D3.A, POWER.2, R21.2, R26.1, R27.2
unnamed: OK1.2 (C), U5.3 (1R)
unnamed: OK2.2 (C), U5.5 (2R)
unnamed: OK1.1 (A), R4.1
unnamed: OK2.1 (A), R3.1
unnamed: N0183-RX.4, U5.2 (1A)
unnamed: N0183-RX.3, U5.1 (1B)
unnamed: N0183-RX.2, U5.6 (2A)
unnamed: N0183-RX.1, U5.7 (2B)
unnamed: C11.1, C17.1, C18.1, OK3.6 (VCC), OK4.6 (VCC), R3.2, R4.2, R17.2, R18.2, TX-DISABLE.2, TX-ENABLE.1, TX-ENABLE.2, U5.4 (1DE), U5.12 (2DE), U5.16 (VCC), U6.4 (V+OUT)
unnamed: N0183-TX.4, U5.14 (1Y)
unnamed: N0183-TX.3, U5.13 (1Z)
unnamed: N0183-TX.2, U5.10 (2Y)
unnamed: N0183-TX.1, U5.11 (2Z)
unnamed: OK3.1 (A), R15.1
unnamed: OK4.1 (A), R16.1
unnamed: OK3.4 (OUT), R18.1, U5.15 (1D)
unnamed: OK4.4 (OUT), R17.1, U5.9 (2D)
unnamed: R20.1, T1.B, Z2.K
unnamed: C23.P$1 (1), U7.1 (BST)
unnamed: C23.P$2 (2), D6.K, L1.P$1 (1), U7.6 (LX)
unnamed: R21.1, R22.2, SJ3.2
unnamed: C4.1, R30.1, R32.2, U7.3 (FB)
OP_CUR_3V3_H: C6.1, POWER.11, R28.2, U4.2 (VOUT)
OP_CUR_5V_H: C4.2, C19.2, L1.P$2 (2), POWER.9, R30.2, R33.2
RX1: OK1.4 (OUT), R5.1; also elsewhere on the board
RX2: OK2.4 (OUT), R6.1; also elsewhere on the board
SCAP: C20.+, D4.A, JP3.1, R19.1
SCAPDRV: JP1.1, R19.2, T1.E
TX1: OK3.2 (C); also elsewhere on the board
TX2: OK4.2 (C); also elsewhere on the board
VSENSE: POWER.3, R27.1, SJ2.1, SJ2.2, SJ3.1, Z1.2 (K); also elsewhere on the board

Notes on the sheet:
Wireless Inexpensive Bathymetry Logger (WIBL)
V 2.4.0 (2022-04-23)

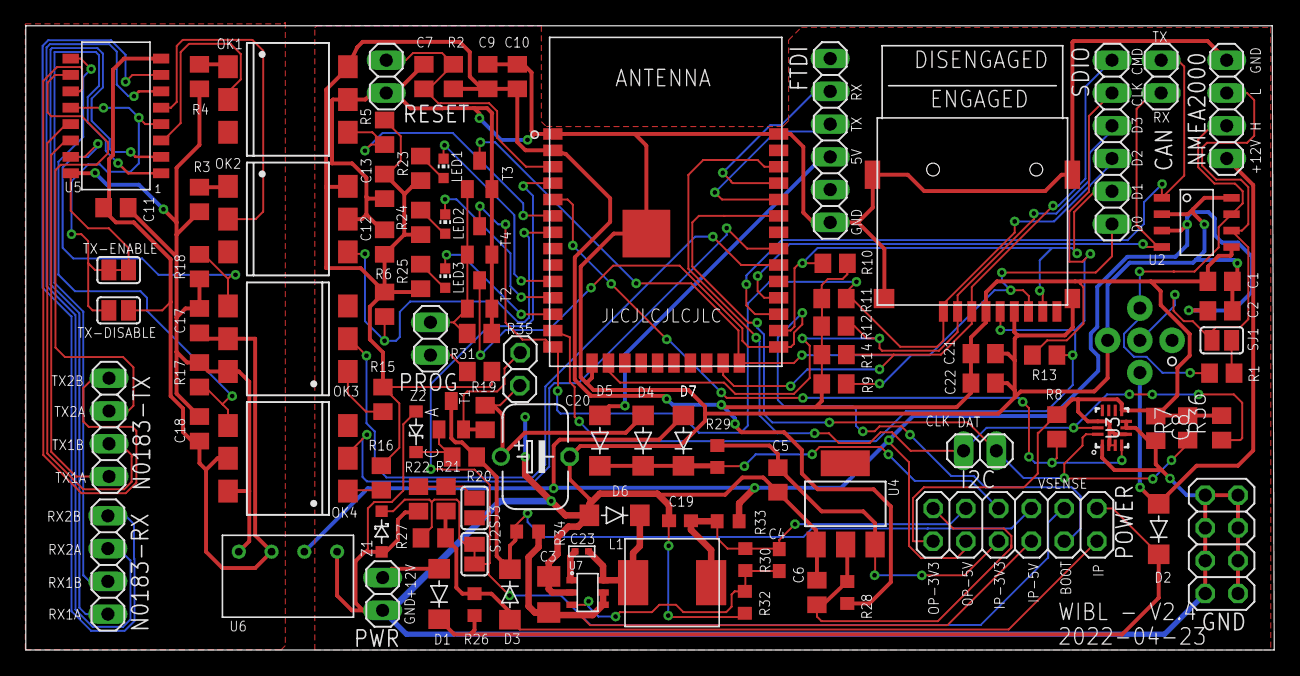
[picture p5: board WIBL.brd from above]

Board: 2 copper layers, 96.8 x 48.4 mm, 105 parts (0 on the bottom side), 70 nets.

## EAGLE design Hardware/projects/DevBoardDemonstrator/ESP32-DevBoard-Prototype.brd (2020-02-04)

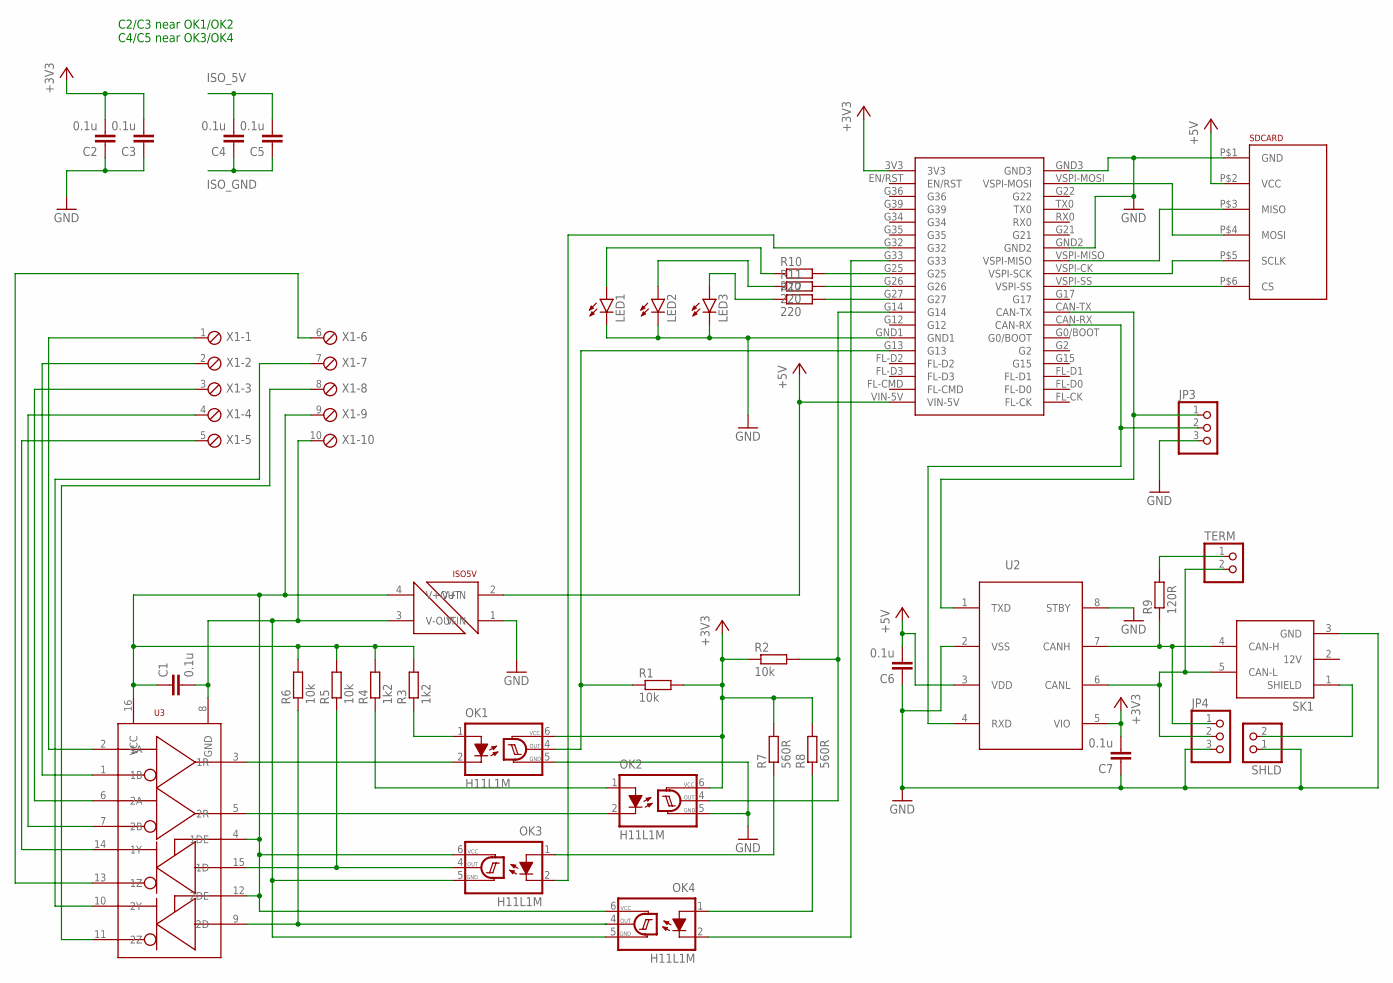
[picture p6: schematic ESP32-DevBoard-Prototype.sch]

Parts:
C1, C2, C3, C4, C5, C6, C7: 0.1u; C050-025X075
ISO5V: RFM-0505S
JP3, JP4: PINHD-1X3; 1X03
LED1, LED2, LED3: LED5MM
OK1, OK2, OK3, OK4: H11L1M; DIL06
R1, R2, R5, R6: 10k; 0207/10
R3, R4: 1k2; 0207/10
R7, R8: 560R; 0207/10
R9: 120R; 0207/10
R10, R11, R12: 220; 0207/10
SDCARD: MICROSD-BREAKOUT
SHLD: PINHD-1X2; 1X02
SK1: NMEA2000-TOPSIDE
TERM: PINHD-1X2; 1X02
U1: ESP32-DEVBOARD
U2: MCP2562-TH; DIP8
U3: SN65C1168; DIP16
X1: MPT10; 10POL254

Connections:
+3V3: C2.2, C3.2, C7.2, OK1.6 (VCC), OK2.6 (VCC), R1.2, R2.1, R7.2, R8.2, U1.3V3, U2.5 (VIO)
+5V: C6.2, ISO5V.2 (V+IN), SDCARD.P$2 (VCC), U1.VIN-5V, U2.3 (VDD)
GND: C2.1, C3.1, C6.1, C7.1, ISO5V.1 (V-IN), JP3.3, JP4.3, LED1.K (C), LED2.K (C), LED3.K (C), OK1.5 (GND), OK2.5 (GND), SDCARD.P$1 (GND), SHLD.1, SK1.3 (GND), U1.GND1, U1.GND2, U1.GND3, U2.2 (VSS), U2.8 (STBY)
ISO_5V: C1.1, C4.2, C5.2, ISO5V.4 (V+OUT), OK3.6 (VCC), OK4.6 (VCC), R3.2, R4.2, R5.2, R6.2, U3.4 (1DE), U3.12 (2DE), U3.16 (VCC), X1.9
ISO_GND: C1.2, C4.1, C5.1, ISO5V.3 (V-OUT), OK3.5 (GND), OK4.5 (GND), U3.8 (GND), X1.10
unnamed: JP3.1, U1.CAN-TX, U2.1 (TXD)
unnamed: SDCARD.P$4 (MOSI), U1.VSPI-MOSI
unnamed: OK3.1 (A), R7.1
unnamed: OK1.2 (C), U3.3 (1R)
unnamed: OK2.2 (C), U3.5 (2R)
unnamed: OK3.4 (OUT), R5.1, U3.15 (1D)
unnamed: OK4.4 (OUT), R6.1, U3.9 (2D)
unnamed: OK1.4 (OUT), R1.1, U1.G13
unnamed: OK2.4 (OUT), R2.2, U1.G14
unnamed: OK1.1 (A), R3.1
unnamed: OK2.1 (A), R4.1
unnamed: OK4.1 (A), R8.1
unnamed: SDCARD.P$3 (MISO), U1.VSPI-MISO
unnamed: OK3.2 (C), U1.G32
unnamed: OK4.2 (C), U1.G33
unnamed: SDCARD.P$5 (SCLK), U1.VSPI-CK (VSPI-SCK)
unnamed: SDCARD.P$6 (CS), U1.VSPI-SS
unnamed: JP3.2, U1.CAN-RX, U2.4 (RXD)
unnamed: JP4.1, R9.1, SK1.4 (CAN-H), U2.7 (CANH)
unnamed: JP4.2, SK1.5 (CAN-L), TERM.2, U2.6 (CANL)
unnamed: R9.2, TERM.1
unnamed: U3.2 (1A), X1.1
unnamed: SHLD.2, SK1.1 (SHIELD)
unnamed: U3.1 (1B), X1.2
unnamed: U3.6 (2A), X1.3
unnamed: U3.7 (2B), X1.4
unnamed: U3.14 (1Y), X1.5
unnamed: U3.13 (1Z), X1.6
unnamed: U3.10 (2Y), X1.7
unnamed: R10.2, U1.G25
unnamed: U3.11 (2Z), X1.8
unnamed: LED3.A, R12.1
unnamed: LED2.A, R11.1
unnamed: LED1.A, R10.1
unnamed: R11.2, U1.G26
unnamed: R12.2, U1.G27

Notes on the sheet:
C2/C3 near OK1/OK2 C4/C5 near OK3/OK4

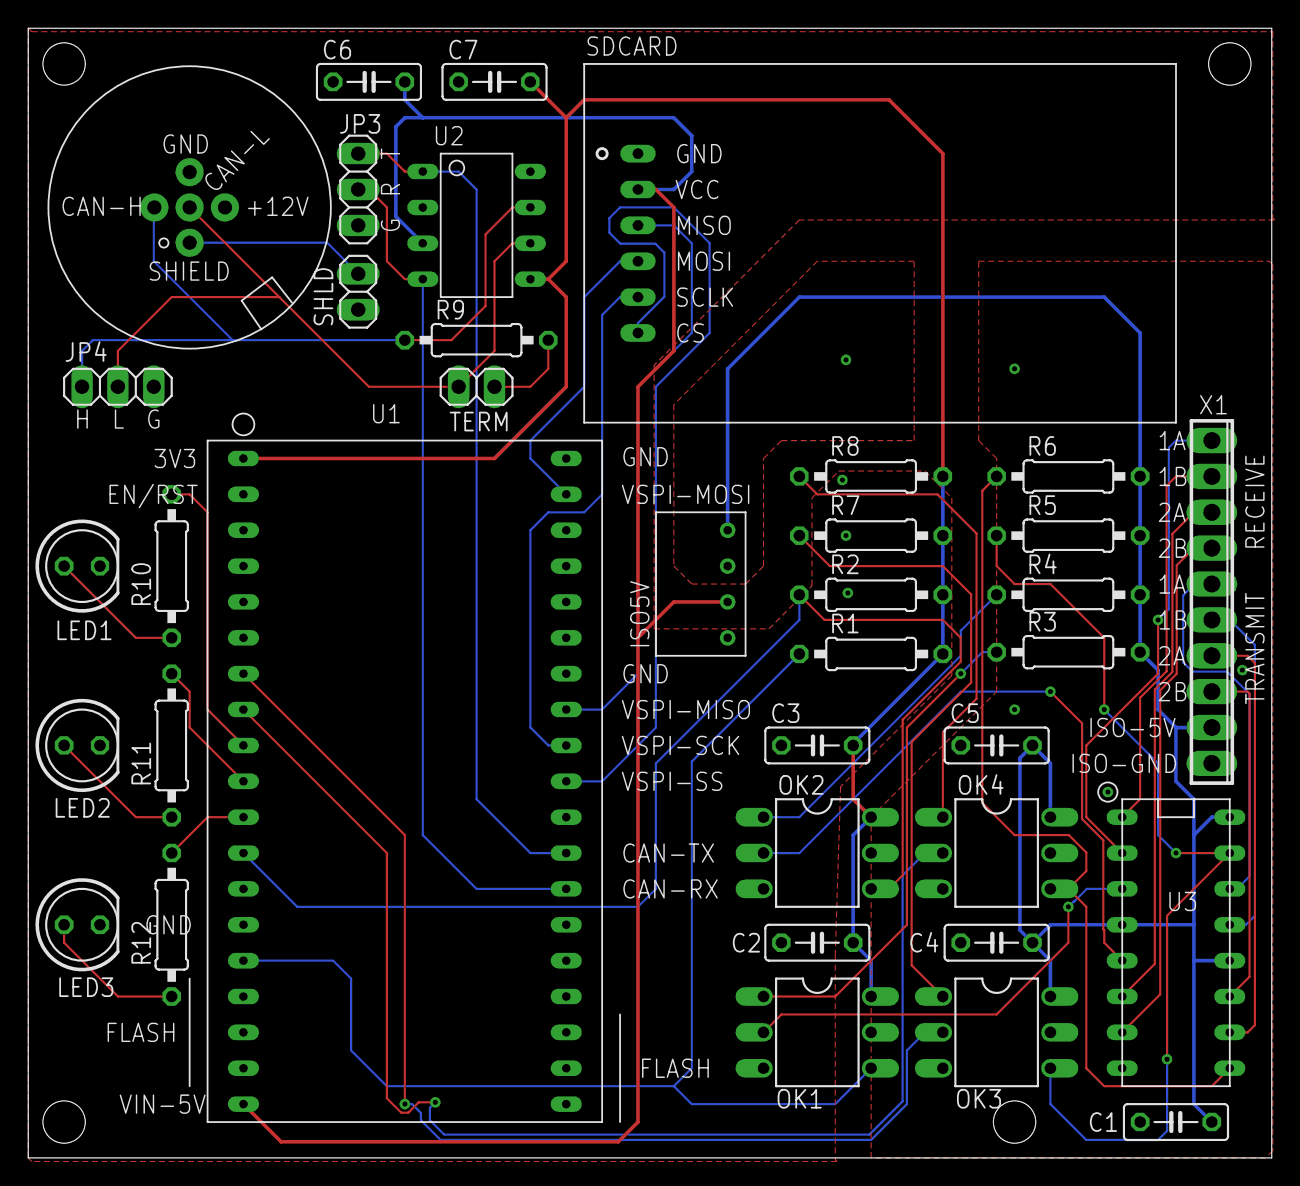
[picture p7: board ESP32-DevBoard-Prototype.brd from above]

Board: 2 copper layers, 88.1 x 80.0 mm, 37 parts (0 on the bottom side), 41 nets.

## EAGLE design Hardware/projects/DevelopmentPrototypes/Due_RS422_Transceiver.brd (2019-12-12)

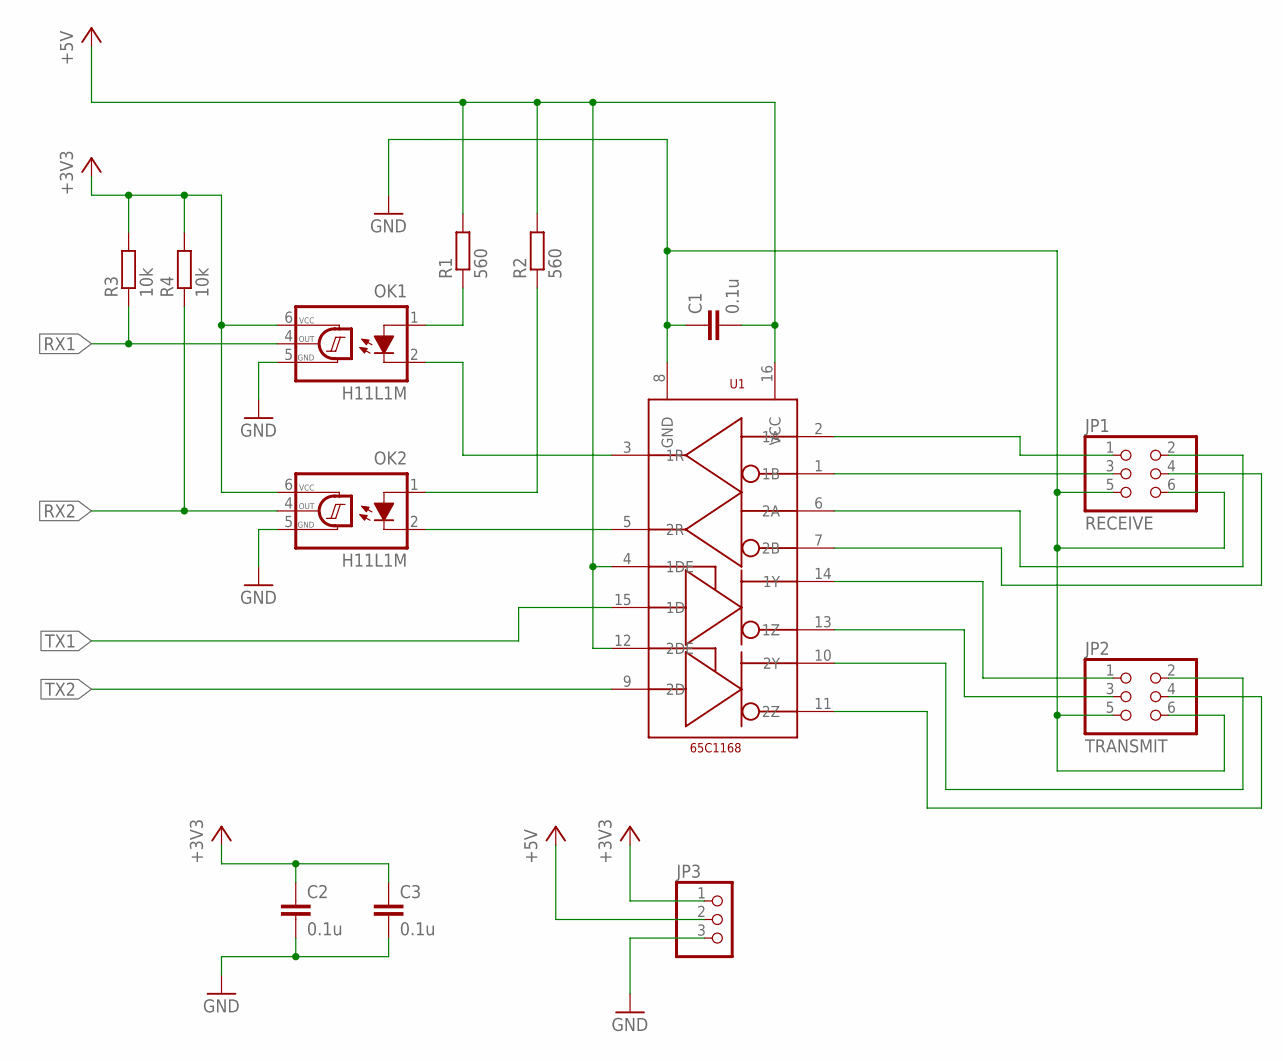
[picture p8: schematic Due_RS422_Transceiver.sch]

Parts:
C1, C2, C3: 0.1u; C050-030X075
JP1: RECEIVE; 2X03
JP2: TRANSMIT; 2X03
JP3: PINHD-1X3; 1X03
OK1, OK2: H11L1M; DIL06
R1, R2: 560; 0204/7
R3, R4: 10k; 0204/7
U1: 65C1168; DIP16

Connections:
+3V3: C2.1, C3.1, JP3.1, OK1.6 (VCC), OK2.6 (VCC), R3.2, R4.2
+5V: C1.2, JP3.2, R1.2, R2.2, U1.4 (1DE), U1.12 (2DE), U1.16 (VCC)
GND: C1.1, C2.2, C3.2, JP1.5, JP1.6, JP2.5, JP2.6, JP3.3, OK1.5 (GND), OK2.5 (GND), U1.8 (GND)
unnamed: OK1.2 (C), U1.3 (1R)
unnamed: OK2.2 (C), U1.5 (2R)
unnamed: OK1.1 (A), R1.1
unnamed: OK2.1 (A), R2.1
unnamed: JP1.3, U1.1 (1B)
unnamed: JP1.1, U1.2 (1A)
unnamed: JP1.2, U1.6 (2A)
unnamed: JP1.4, U1.7 (2B)
unnamed: JP2.1, U1.14 (1Y)
unnamed: JP2.3, U1.13 (1Z)
unnamed: JP2.2, U1.10 (2Y)
unnamed: JP2.4, U1.11 (2Z)
RX1: OK1.4 (OUT), R3.1
RX2: OK2.4 (OUT), R4.1
TX1: U1.15 (1D)
TX2: U1.9 (2D)

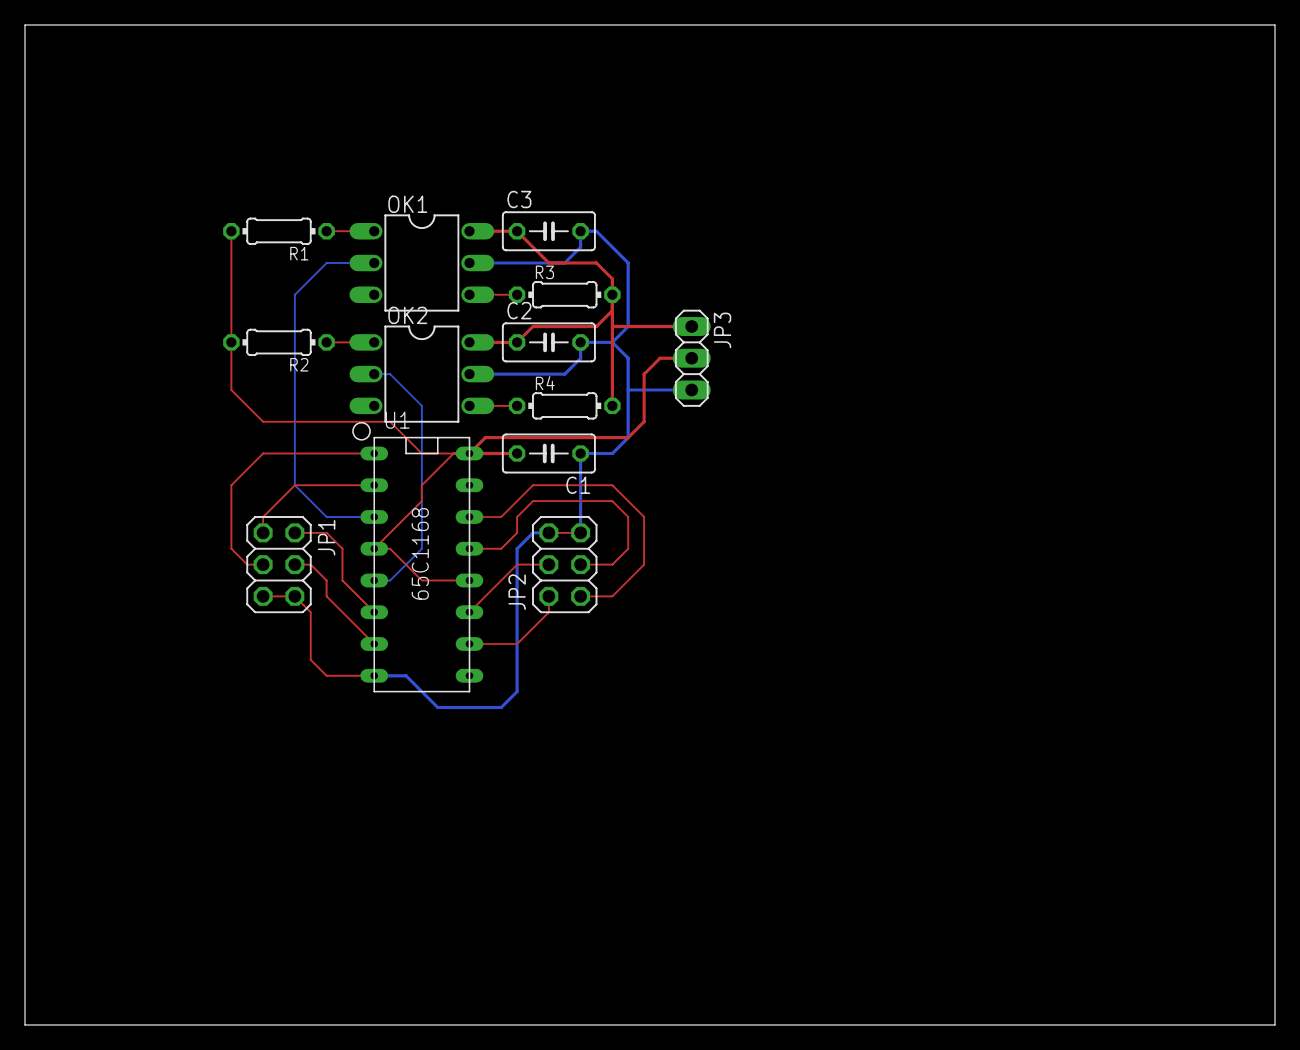
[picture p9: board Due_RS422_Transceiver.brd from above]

Board: 2 copper layers, 100.0 x 80.0 mm, 13 parts (0 on the bottom side), 17 nets.

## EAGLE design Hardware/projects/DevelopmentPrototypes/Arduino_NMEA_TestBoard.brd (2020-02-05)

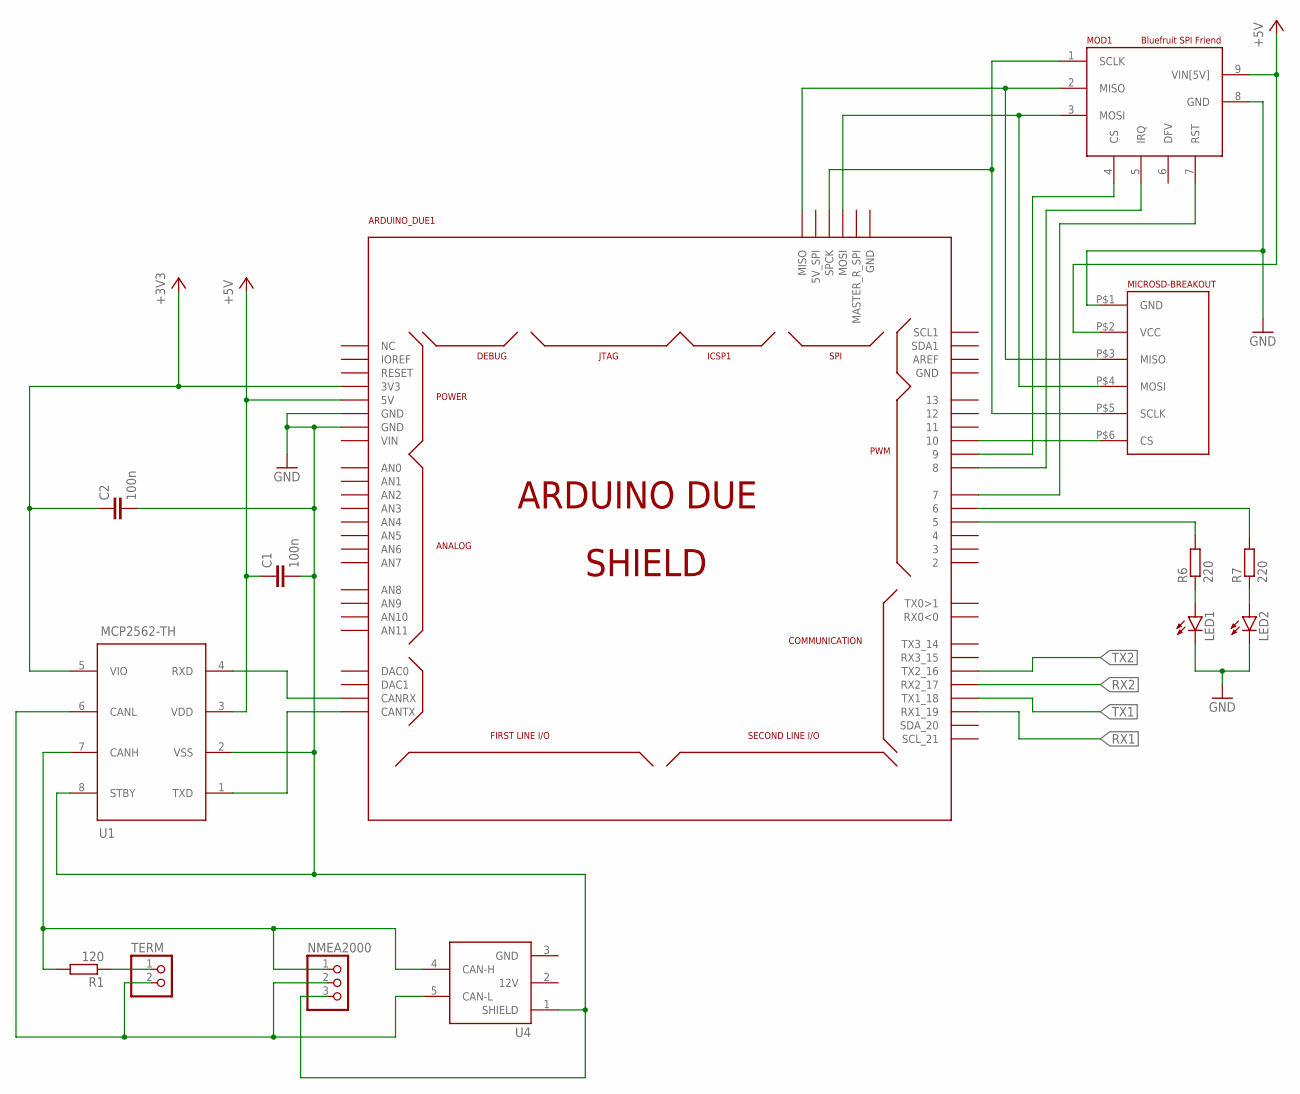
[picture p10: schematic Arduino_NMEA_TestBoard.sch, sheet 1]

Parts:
ARDUINO_DUE1: ARDUINO_DUE_SHIELD
C1, C2: 100n; C050-025X075
LED1, LED2: LED5MM
MICROSD-BREAKOUT: MICROSD-BREAKOUT
MOD1: BLUEFRUIT-SPI-FRIEND; BLE_SPIFRIEND
NMEA2000: PINHD-1X3; 1X03
R1: 120; 0207/10
R6, R7: 220; 0207/10
TERM: PINHD-1X2; 1X02
U1: MCP2562-TH; DIP8
U4: NMEA2000-TOPSIDE

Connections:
+3V3: ARDUINO_DUE1.3V3, C2.1, U1.5 (VIO); also elsewhere on the board
+5V: ARDUINO_DUE1.5V0 (5V), C1.1, MICROSD-BREAKOUT.P$2 (VCC), MOD1.9 (VIN[5V]), U1.3 (VDD); also elsewhere on the board
GND: ARDUINO_DUE1.GND, ARDUINO_DUE1.GND_1 (GND), C1.2, C2.2, LED1.K (C), LED2.K (C), MICROSD-BREAKOUT.P$1 (GND), MOD1.8 (GND), NMEA2000.3, U1.2 (VSS), U1.8 (STBY), U4.1 (SHIELD); also elsewhere on the board
unnamed: ARDUINO_DUE1.SPCK, MICROSD-BREAKOUT.P$5 (SCLK), MOD1.1 (SCLK)
unnamed: ARDUINO_DUE1.CANRX, U1.4 (RXD)
unnamed: ARDUINO_DUE1.CANTX, U1.1 (TXD)
unnamed: NMEA2000.2, TERM.2, U1.6 (CANL), U4.5 (CAN-L)
unnamed: NMEA2000.1, R1.2, U1.7 (CANH), U4.4 (CAN-H)
unnamed: ARDUINO_DUE1.MISO, MICROSD-BREAKOUT.P$3 (MISO), MOD1.2 (MISO)
unnamed: ARDUINO_DUE1.MOSI, MICROSD-BREAKOUT.P$4 (MOSI), MOD1.3 (MOSI)
unnamed: R1.1, TERM.1
unnamed: ARDUINO_DUE1.10, MICROSD-BREAKOUT.P$6 (CS)
unnamed: ARDUINO_DUE1.9, MOD1.4 (CS)
unnamed: ARDUINO_DUE1.8, MOD1.5 (IRQ)
unnamed: ARDUINO_DUE1.7, MOD1.7 (RST)
unnamed: ARDUINO_DUE1.5, R6.2
unnamed: ARDUINO_DUE1.6, R7.2
unnamed: LED1.A, R6.1
unnamed: LED2.A, R7.1
RX1: ARDUINO_DUE1.19 (RX1_19); also elsewhere on the board
RX2: ARDUINO_DUE1.17 (RX2_17); also elsewhere on the board
TX1: ARDUINO_DUE1.18 (TX1_18); also elsewhere on the board
TX2: ARDUINO_DUE1.16 (TX2_16); also elsewhere on the board

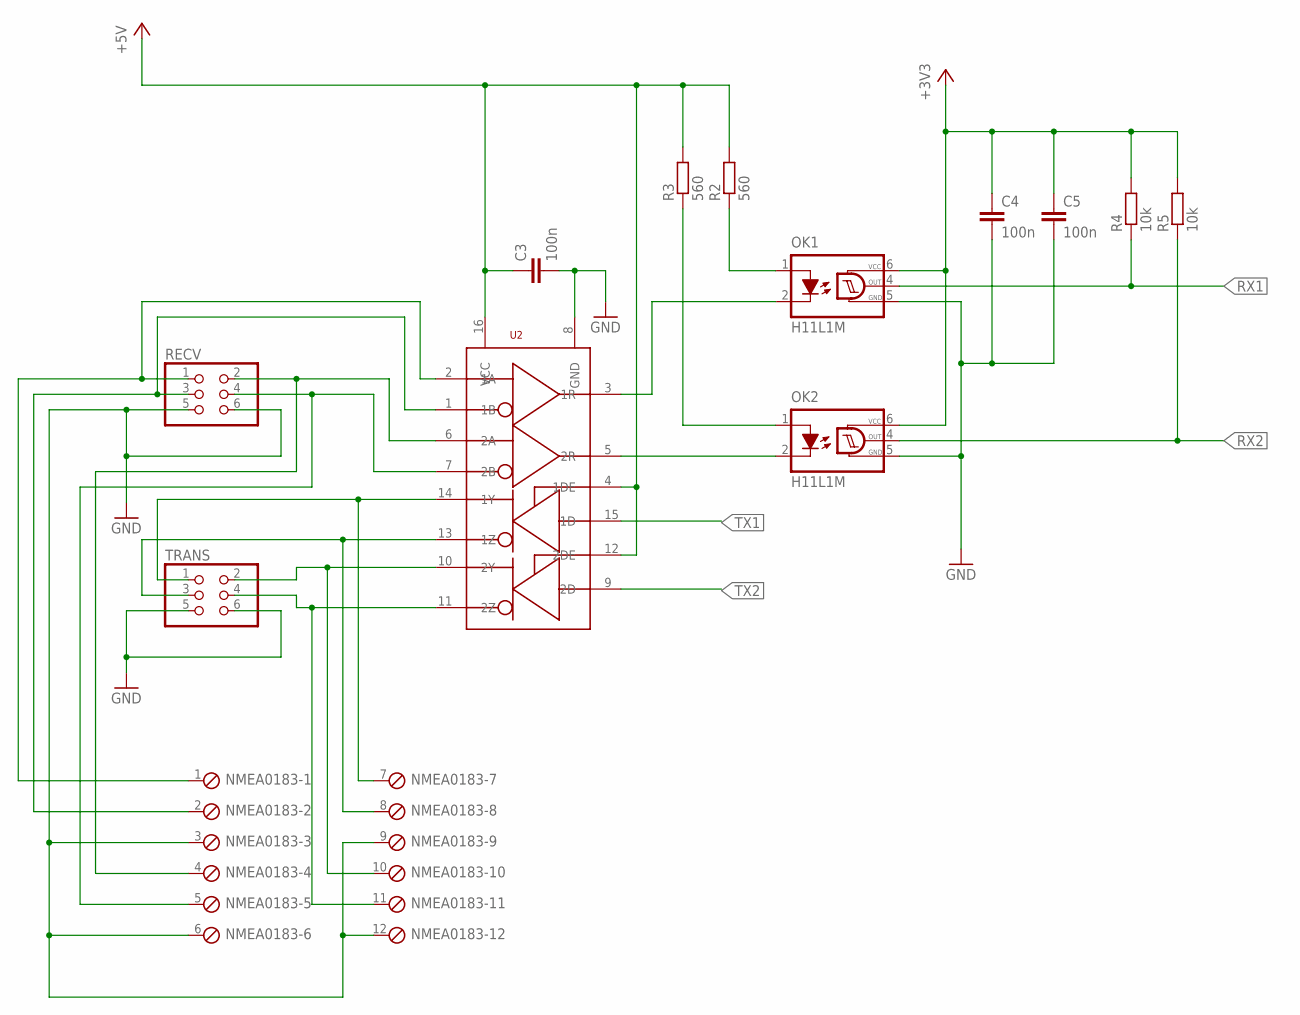
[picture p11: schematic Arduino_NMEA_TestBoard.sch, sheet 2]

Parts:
C3, C4, C5: 100n; C050-025X075
NMEA0183: MPT12; 12POL254
OK1, OK2: H11L1M; DIL06
R2, R3: 560; 0207/10
R4, R5: 10k; 0207/10
RECV: PINHD-2X3; 2X03
TRANS: PINHD-2X3; 2X03
U2: SN65C1168; DIP16

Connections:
+3V3: C4.1, C5.1, OK1.6 (VCC), OK2.6 (VCC), R4.2, R5.2; also elsewhere on the board
+5V: C3.1, R2.2, R3.2, U2.4 (1DE), U2.12 (2DE), U2.16 (VCC); also elsewhere on the board
GND: C3.2, C4.2, C5.2, NMEA0183.3, NMEA0183.6, NMEA0183.9, NMEA0183.12, OK1.5 (GND), OK2.5 (GND), RECV.5, RECV.6, TRANS.5, TRANS.6, U2.8 (GND); also elsewhere on the board
unnamed: OK2.2 (C), U2.5 (2R)
unnamed: OK1.2 (C), U2.3 (1R)
unnamed: OK1.1 (A), R2.1
unnamed: OK2.1 (A), R3.1
unnamed: NMEA0183.1, RECV.1, U2.2 (1A)
unnamed: NMEA0183.2, RECV.3, U2.1 (1B)
unnamed: NMEA0183.4, RECV.2, U2.6 (2A)
unnamed: NMEA0183.5, RECV.4, U2.7 (2B)
unnamed: NMEA0183.8, TRANS.3, U2.13 (1Z)
unnamed: NMEA0183.10, TRANS.2, U2.10 (2Y)
unnamed: NMEA0183.7, TRANS.1, U2.14 (1Y)
unnamed: NMEA0183.11, TRANS.4, U2.11 (2Z)
RX1: OK1.4 (OUT), R4.1; also elsewhere on the board
RX2: OK2.4 (OUT), R5.1; also elsewhere on the board
TX1: U2.15 (1D); also elsewhere on the board
TX2: U2.9 (2D); also elsewhere on the board

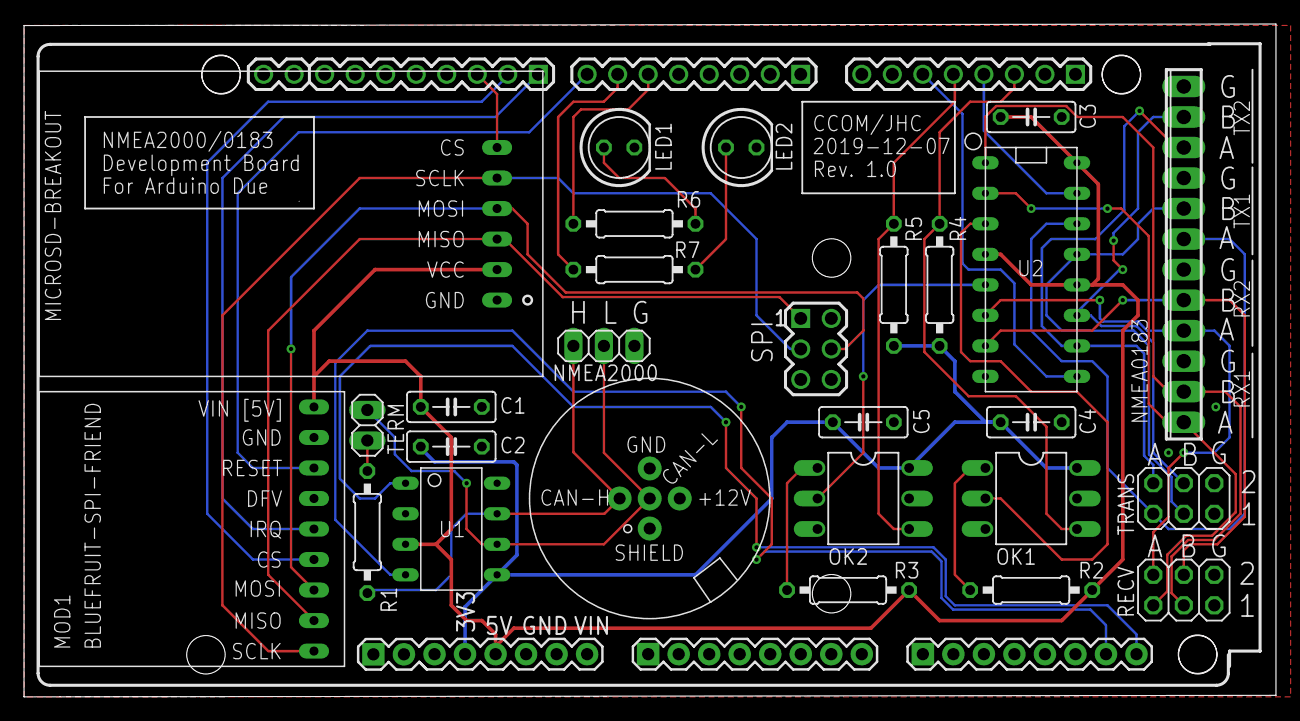
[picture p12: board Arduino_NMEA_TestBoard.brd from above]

Board: 2 copper layers, 104.2 x 56.0 mm, 27 parts (0 on the bottom side), 35 nets.

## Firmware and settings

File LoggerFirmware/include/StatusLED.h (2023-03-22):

/*!\file StatusLED.h
 * \brief Interface for status LED management
 *
 * The logger has status LEDs to indicate what it's doing, and things like a full
 * SD card, or bad card, etc.  This code manages the colours and specifics of
 * the system.
 *
 * Copyright (c) 2019, University of New Hampshire, Center for Coastal and Ocean Mapping.
 *
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
 * THE SOFTWARE IS PROVIDED "AS IS", WITHOUT WARRANTY OF ANY KIND, EXPRESS OR
 * IMPLIED, INCLUDING BUT NOT LIMITED TO THE WARRANTIES OF MERCHANTABILITY, FITNESS
 * FOR A PARTICULAR PURPOSE AND NONINFRINGEMENT. IN NO EVENT SHALL THE AUTHORS
 * OR COPYRIGHT HOLDERS BE LIABLE FOR ANY CLAIM, DAMAGES OR OTHER LIABILITY,
 * WHETHER IN AN ACTION OF CONTRACT, TORT OR OTHERWISE, ARISING FROM, OUT OF
 * OR IN CONNECTION WITH THE SOFTWARE OR THE USE OR OTHER DEALINGS IN THE SOFTWARE.
 */

#ifndef __STATUS_LED_H__
#define __STATUS_LED_H__

#include <Arduino.h>

#if defined(ARDUINO_ARCH_ESP32) || defined(ESP32)
#ifdef PROTOTYPE_LOGGER

// The prototype logger is made up of standard modules, and an ESP32 development
// module to do the work.  There isn't a lot of use for this now that WIBL exists,
// but it's here for historical reasons.

/// ESP32 GPIO pin to use for the RED indicator LED
#define DEFAULT_RED_LED_PIN 25
/// ESP32 GPIO pin to use for the GREEN indicator LED
#define DEFAULT_GREEN_LED_PIN 26
/// ESP32 GPIO pin to use for the BLUE indiator LED
#define DEFAULT_BLUE_LED_PIN 27

#elif defined(BUILD_NEMO30)

// The NEMO-30 implementation of WIBL uses different LED pins from the standard model
// due to certain pins being required for other purposes with its particular hardware.

/// ESP32 GPIO pin to use for the RED indicator LED
#define DEFAULT_RED_LED_PIN 34
/// ESP32 GPIO pin to use for the GREEN indicator LED
#define DEFAULT_GREEN_LED_PIN 35
/// ESP32 GPIO pin to use for the BLUE indicator LED
#define DEFAULT_BLUE_LED_PIN 32

#else

// The standard setup for WIBL

/// ESP32 GPIO pin to use for the RED indicator LED
#define DEFAULT_RED_LED_PIN     25
/// ESP32 GPIO pin to use for the GREEN indicator LED
#define DEFAULT_GREEN_LED_PIN   26
/// ESP32 GPIO pin to use for the BLUE indicator LED
#define DEFAULT_BLUE_LED_PIN    27
#endif
#endif

#if defined(__SAM3X8E__)

// As a legacy, there is an option to use an Arduino Due for the logger prototype
// (at the breadboard level).

/// Arduino Due GPIO pin to use for the RED indicator LED
#define DEFAULT_RED_LED_PIN 8
/// Arduino Due GPIO pin to use for the GREEN indicator LED
#define DEFAULT_GREEN_LED_PIN 9
/// Arduino Due GPIO pin to use for the BLUE indicator LED
#define DEFAULT_BLUE_LED_PIN 22
#endif

/// \class StatusLED
/// \brief Controller for the status LEDs, translating status to colours/flashes
///
/// The logger can have up to three status LEDs, nominally a common-cathode RGB variety
/// to show the status of the logger (e.g., initialising, normal behaviour, error condition, card full,
/// etc.)  If a RGB led isn't available, separate red and green LEDs give most of the behaviours.

class StatusLED {
public:
    /// \brief Default constructor for the LED manager
    StatusLED(int red_ping = DEFAULT_RED_LED_PIN,
              int green_pin = DEFAULT_GREEN_LED_PIN,
              int blue_pin = DEFAULT_BLUE_LED_PIN);
    
    /// \enum Status
    /// \brief Known states that the logger can be in
    enum Status {
        sINITIALISING,  ///< The logger is initialising (probably very brief)
        sNORMAL,        ///< Normal operations
        sCARD_FULL,     ///< The SD card for data is full and needs service
        sFATAL_ERROR,   ///< A fatal error has occurred, and the logger needs service
        sSTOPPED        ///< Logger is stopped for shutdown
    };
    
    /// \brief Set the status for the LED
    void SetStatus(Status status);
    
    /// \brief Indicate that a data event has occurred
    void TriggerDataIndication(void);
    
    /// \brief Switch state of LED if time period has expired
    void ProcessFlash(void);
    
private:
    int             led_pins[3];        ///< GPIO pin numbers to use for the three LED channels
    boolean         led_state[3];       ///< Flags indicating whether each LED should be on or off
    boolean         led_flasher;        ///< Flag indicating whether the LEDs should be flashing or not
    unsigned long   last_change_time;   ///< Last millis() when the flash status changed
    unsigned long   on_period;          ///< Number of millis() for each flash
    unsigned long   data_end_time;      ///< Time after which to turn off data light
    unsigned long   data_flash_duration;    ///< Number of millis() for data event to show
    
    /// \brief Turn on the data LED for an event indication
    void DataLEDOn(void);
    
    /// \brief Turn off the data LED
    void DataLEDOff(void);

    /// \enum Colour
    /// \brief Translated version of the states
    enum Colour {
        cINITIALISING,  ///< Colours for initialisation
        cNORMAL,        ///< Colours for normal behaviour
        cCARD_FULL,     ///< Colours for full SD card
        cALARM,         ///< Colours for an alarm condition
        cSTOPPED        ///< Colours for a stopped logger
    };
    
    /// \brief Set the specific colours used for each state, and the flash status
    void SetColour(Colour colour, boolean flash = false);
};

#endif

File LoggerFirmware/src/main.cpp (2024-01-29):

/*!\file LoggerFirmware.ino
 * \brief Arduino sketch for the NMEA2000 depth/position logger with network time
 *
 * This provides the Arduino-style interface to a NMEA2000 network data logger that's
 * suitable for recording data for Volunteer Geographic Information collection at sea
 * (in keeping with IHO Crowdsourced Bathymetry Working Group recommendations as defined
 * in IHO publication B-12).
 *
 * Copyright (c) 2019, University of New Hampshire, Center for Coastal and Ocean Mapping.
 *
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
 * THE SOFTWARE IS PROVIDED "AS IS", WITHOUT WARRANTY OF ANY KIND, EXPRESS OR
 * IMPLIED, INCLUDING BUT NOT LIMITED TO THE WARRANTIES OF MERCHANTABILITY, FITNESS
 * FOR A PARTICULAR PURPOSE AND NONINFRINGEMENT. IN NO EVENT SHALL THE AUTHORS
 * OR COPYRIGHT HOLDERS BE LIABLE FOR ANY CLAIM, DAMAGES OR OTHER LIABILITY,
 * WHETHER IN AN ACTION OF CONTRACT, TORT OR OTHERWISE, ARISING FROM, OUT OF
 * OR IN CONNECTION WITH THE SOFTWARE OR THE USE OR OTHER DEALINGS IN THE SOFTWARE.
 */

#define ESP32_CAN_TX_PIN GPIO_NUM_16
#define ESP32_CAN_RX_PIN GPIO_NUM_17

#include <NMEA2000_CAN.h> /* This auto-generates the NMEA2000 global for bus control */
#include "ArduinoJson.h"
#include "N2kLogger.h"
#include "serial_number.h"
#include "SerialCommand.h"
#include "StatusLED.h"
#include "MemController.h"
#include "IMULogger.h"
#include "SupplyMonitor.h"
#include "Configuration.h"
#include "HeapMonitor.h"

/// Hardware version for the logger implementation (for NMEA2000 declaration)
#define LOGGER_HARDWARE_VERSION "2.4.1"

const unsigned long TransmitMessages[] PROGMEM={0}; ///< List of messages the logger transmits (null set)
const unsigned long ReceiveMessages[] PROGMEM =
  {126992UL /*System Time */,
   127257UL /* Attitude */,
   128267UL /* Water Depth */,
   129026UL /* Course and Speed Over Ground */,
   129029UL /* GNSS Position */,
   130311UL /* Environmental Parameters */,
   130312UL /* Temperature */,
   130313UL /* Humidity */,
   130314UL /* Pressure */,
   130316UL /* Extended Temperature */,
   0
  }; ///< List if messages that the logger expects to receive

nmea::N2000::Logger     *N2000Logger = nullptr;     ///< Pointer for NMEA2000 CANbus logger object
nmea::N0183::Logger     *N0183Logger = nullptr;     ///< Pointer for serial NMEA data logger object
imu::Logger             *IMULogger = nullptr;       ///< Pointer for local IMU data logger
logger::Manager         *logManager = nullptr;      ///< SD log file manager object
StatusLED               *LEDs = nullptr;            ///< Pointer to the status LED manager object
SerialCommand           *CommandProcessor = nullptr;///< Pointer for the command processor object
mem::MemController      *memController = nullptr;   ///< Pointer for the storage abstraction
logger::SupplyMonitor   *supplyMonitor = nullptr;   ///< Pointer for the supply voltage monitoring code

/// \brief Primary setup code for the logger
///
/// Primary setup for the logger.  This needs to configure the hardware Serial object used
/// for reporting debug information (and taking commands), then setting up the primary objects,
/// then starting the NMEA2000 bus interface.  This should allow messages to start to be
/// received through the CAN bus controller.

void setup()
{
    logger::HeapMonitor heap;
    // We need to get these now, since starting the Serial interface might change things
    uint32_t heap_size = heap.HeapSize();
    uint32_t heap_free = heap.CurrentSize();

    Serial.begin(115200);

    Serial.printf("*\n*\n*\n* BOOTING WIBL DATA LOGGER, FIRMWARE VERSION %s\n*\n* For more information: http://wibl.ccom.unh.edu\n*\n*\n*\n", logger::FirmwareVersion());

    Serial.printf("DBG: At boot, heap is %d B (%d B free)\n", heap_size, heap_free);
    Serial.printf("DBG: ");
    heap.FlashMemoryReport(Serial);
    Serial.printf("\n");

    Serial.printf("DBG: After serial start, free heap = %d B, delta = %d B\n", heap.CurrentSize(), heap.DeltaSinceLast());

    Serial.println("Configuring LED indicators ...");
    LEDs = new StatusLED();

    Serial.println("Setting up LED indicator for initialising ...");
    LEDs->SetStatus(StatusLED::Status::sINITIALISING);
    Serial.printf("DBG: After LED start and configuration, free heap = %d B, delta = %d B\n", heap.CurrentSize(), heap.DeltaSinceLast());

    Serial.println("Checking for stable configuration ...");
    if (!logger::ConfigJSON::SetStableConfig()) {
        Serial.println("ERR: Failed to set stable configuration ... halting.");
        LEDs->SetStatus(StatusLED::Status::sFATAL_ERROR);
        while (1) {
            LEDs->ProcessFlash(); /* Busy loop to make sure the LED flashes */
            delay(100);
        }
    } else {
        Serial.println("INF: Configuration is now:");
        DynamicJsonDocument config(logger::ConfigJSON::ExtractConfig(true));
        String config_str;
        serializeJsonPretty(config, config_str);
        Serial.println(config_str);
    }
    
    Serial.println("Bringing up Storage Controller ...");
    memController = mem::MemControllerFactory::Create();
    
    Serial.println("Starting memory interface ...");
    #ifdef DEBUG_LOG_MANAGER
    Serial.println("DBG: Ignoring memory sub-system for debug purposes.");
    #else
    if (!memController->Start()) {
        Serial.println("ERR: Memory system didn't start ... halting.");
        // Card is not present, or didn't start ... that's a fatal error
        LEDs->SetStatus(StatusLED::Status::sFATAL_ERROR);
        while (1) {
            LEDs->ProcessFlash(); /* Busy loop to make sure the LED flashes */
            delay(100);
        }
    }
    #endif

    Serial.printf("DBG: After memory interface start, free heap = %d B, delta = %d B\n", heap.CurrentSize(), heap.DeltaSinceLast());
    Serial.println("Configuring logger manager ...");
    logManager = new logger::Manager(LEDs, memController);
    Serial.printf("DBG: After log manager start, free heap = %d B, delta = %d B\n", heap.CurrentSize(), heap.DeltaSinceLast());
    logManager->AddInventory();
    Serial.printf("DBG: After inventory object start, free heap = %d B, delta = %d B\n", heap.CurrentSize(), heap.DeltaSinceLast());
    
    bool start_nmea_2000, start_nmea_0183, start_motion_sensor;
    if (logger::LoggerConfig.GetConfigBinary(logger::Config::ConfigParam::CONFIG_NMEA2000_B, start_nmea_2000)
            && start_nmea_2000) {
        Serial.println("Configuring NEMA2000 logger ...");
        N2000Logger = new nmea::N2000::Logger(&NMEA2000, logManager);

        Serial.printf("DBG: After NMEA2000 logger start, free heap = %d B, delta = %d B\n", heap.CurrentSize(), heap.DeltaSinceLast());
    }
  
    if (logger::LoggerConfig.GetConfigBinary(logger::Config::ConfigParam::CONFIG_NMEA0183_B, start_nmea_0183)
            && start_nmea_0183) {
        Serial.println("Configuring NMEA0183 logger (and configuring serial ports)...");
        N0183Logger = new nmea::N0183::Logger(logManager);

        Serial.printf("DBG: After NMEA0183 logger start, free heap = %d B, delta = %d B\n", heap.CurrentSize(), heap.DeltaSinceLast());
    }

    if (logger::LoggerConfig.GetConfigBinary(logger::Config::ConfigParam::CONFIG_MOTION_B, start_motion_sensor)
            && start_motion_sensor) {
        Serial.println("Configuring IMU logger ...");
        IMULogger = new imu::Logger(logManager);

        Serial.printf("DBG: After IMU logger start, free heap = %d B, delta = %d B\n", heap.CurrentSize(), heap.DeltaSinceLast());
    }

    Serial.println("Configuring command processor ...");
    CommandProcessor = new SerialCommand(N2000Logger, N0183Logger, logManager, LEDs);

    Serial.printf("DBG: After SerialCommand start, free heap = %d B, delta = %d B\n", heap.CurrentSize(), heap.DeltaSinceLast());

    Serial.println("Starting log manager interface to SD card ...");
    logManager->StartNewLog();

    Serial.printf("DBG: After new log file start, free heap = %d B, delta = %d B\n", heap.CurrentSize(), heap.DeltaSinceLast());
  
    if (start_nmea_2000) {
        Serial.println("Starting NMEA2000 bus interface ...");
        NMEA2000.SetProductInformation(GetSerialNumberString(),
                                    1,
                                    "Seabed 2030 NMEA2000 Logger",
                                    N2000Logger->SoftwareVersion().c_str(),
                                    LOGGER_HARDWARE_VERSION
                                    );
        NMEA2000.SetDeviceInformation(GetSerialNumber(),
                                    130,  /* Device Function: PC gateway */
                                    25,   /* Device Class: Inter/Intranetwork Device */
                                    2046  /* */
                                    );
        NMEA2000.SetMode(tNMEA2000::N2km_ListenAndNode, 25);
        NMEA2000.EnableForward(false);
        NMEA2000.ExtendTransmitMessages(TransmitMessages);
        NMEA2000.ExtendReceiveMessages(ReceiveMessages);
        NMEA2000.AttachMsgHandler(N2000Logger);

        NMEA2000.Open();

        Serial.printf("DBG: After NMEA2000 interface start, free heap = %d B, delta = %d B\n", heap.CurrentSize(), heap.DeltaSinceLast());
    }

    Serial.println("Bringing up supply voltage monitoring ...");
    supplyMonitor = new logger::SupplyMonitor();

    Serial.printf("DBG: After voltage monitoring start, free heap = %d B, delta = %d B\n", heap.CurrentSize(), heap.DeltaSinceLast());

    Serial.println("Setup complete, setting status for normal operations.");
    LEDs->SetStatus(StatusLED::Status::sNORMAL);

    heap_free = heap.CurrentSize();
    Serial.printf("DBG: After boot and configuration, free heap = %d B.\n", heap_free);
}

/// \brief General processing loop code for the logger.
///
/// General processing loop.  The code needs to service all of the objects that need
/// timely polling, including the NMEA2000 message stack, flashing the status LEDs,
/// if required, and then checking for (and executing) any commands provided by the
/// user either on the hardware Serial link or through the Bluetooth LE UART, if there's
/// a client configured.

void loop()
{
    if (N2000Logger != nullptr) {
        NMEA2000.ParseMessages();
    }
    if (N0183Logger != nullptr) {
        N0183Logger->ProcessMessages();
    }
    if (IMULogger != nullptr) {
        IMULogger->TransferData();
    }
    if (LEDs != nullptr) {
        LEDs->ProcessFlash();
    }
    if (CommandProcessor != nullptr) {
        CommandProcessor->ProcessCommand();
    }
    uint16_t supply_voltage;
    if (supplyMonitor->EmergencyPower(&supply_voltage)) {
        // Eek!  Power went out, so we need to stop logging ASAP
        //Serial.printf("DBG: Supply voltage ADC dropped to %hu\n", supply_voltage);
        CommandProcessor->EmergencyStop();
    }
}

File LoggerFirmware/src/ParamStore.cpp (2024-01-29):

/*! \file ParamStore.cpp
 *  \brief Implementation of a non-volatile memory parameter store for the logger.
 *
 * In order to provide abstracted storage of configuration parameters, this code generates a
 * factory for the particular hardware implementation, and a sub-class implementation for
 * known hardware.
 *
 * Copyright (c) 2020, University of New Hampshire, Center for Coastal and Ocean Mapping.
 *
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
 * THE SOFTWARE IS PROVIDED "AS IS", WITHOUT WARRANTY OF ANY KIND, EXPRESS OR
 * IMPLIED, INCLUDING BUT NOT LIMITED TO THE WARRANTIES OF MERCHANTABILITY, FITNESS
 * FOR A PARTICULAR PURPOSE AND NONINFRINGEMENT. IN NO EVENT SHALL THE AUTHORS
 * OR COPYRIGHT HOLDERS BE LIABLE FOR ANY CLAIM, DAMAGES OR OTHER LIABILITY,
 * WHETHER IN AN ACTION OF CONTRACT, TORT OR OTHERWISE, ARISING FROM, OUT OF
 * OR IN CONNECTION WITH THE SOFTWARE OR THE USE OR OTHER DEALINGS IN THE SOFTWARE.
 */

#include "ParamStore.h"

#if defined(ARDUINO_ARCH_ESP32) || defined(ESP32)

#include "FS.h"
#include "SPIFFS.h"
#include "LittleFS.h"

/// \class SPIFSParamStore
/// \brief Implement a key-value pair object in flash storage on the SPIFFS module in the ESP32
class SPIFSParamStore : public ParamStore {
public:
    /// Default constructor for the sub-class, which brings up the SPIFFS system, which causes the
    /// file-system part of the flash memory to be formatted if it hasn't been already.  This may take a
    /// little extra time when this is first called.  Since this is likely to be when the system is brought up
    /// in manufacturing, it shouldn't be too much of a problem.
    
    SPIFSParamStore(void)
    {
        if (!SPIFFS.begin(true)) {
            // "true" here forces a format of the FFS if it isn't already
            // formatted (which will cause it to initially fail).
            Serial.println("ERR: SPIFFS mount failed.");
        }
        size_t filesystem_size = SPIFFS.totalBytes();
        size_t used_size = SPIFFS.usedBytes();
        Serial.println(String("INFO: SPI FFS total ") + filesystem_size + "B, used " + used_size + "B");
    }
    
    /// Empty default destructor to allow for sub-classing if required.
    
    virtual ~SPIFSParamStore(void)
    {
    }
    
private:
    /// Set a key-value pair by constructing a file with the name of the key in the SPIFFS file-system
    /// space, and writing the value into it.
    ///
    /// \param key      Recognition name for the value to store.
    /// \param value    Data to write for the key.
    /// \return True if the file was created and written successfully, otherwise false.
    
    bool set_key(String const& key, String const& value)
    {
        fs::File f = SPIFFS.open(String("/") + key + ".par", FILE_WRITE, true);
        if (!f) {
            Serial.printf("ERR: failed to write config key |%s| to filesystem.\n", key.c_str());
            return false;
        }
        f.print(value);
        f.close();
        return true;
    }
    
    /// Get the value of a key-value pair by looking for the file corresponding to the key name in the
    /// SPIFFS file-system, and reading the contents.
    ///
    /// \param key  Recognition name for the value to retrieve
    /// \param value    Reference for where to store the value retrieved.
    /// \return True if the value was successfully retrieved, otherwise false.
    
    bool get_key(String const& key, String& value)
    {
        String filename(String("/") + key + ".par");
        if (!SPIFFS.exists(filename)) {
            File f = SPIFFS.open(filename, FILE_WRITE, true);
            f.close();
        }
        fs::File f = SPIFFS.open(filename, FILE_READ);
        if (!f) {
            Serial.printf("ERR: failed to find config key |%s| in filesystem.\n", key.c_str());
            value = "";
            return false;
        }
        value = f.readString();
        f.close();
        return true;
    }
};
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

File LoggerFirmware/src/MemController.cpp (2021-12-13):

/*!\file MemController.cpp
 * \brief Abstract interface to start the memory system used for log files
 *
 * Depending on the configuration of the logger, the code can write to either an SD card
 * using the SPI interface, or to an eMMC chip using the SDIO/MMC interface.  This object
 * starts the right Arduino interface components for the appropriate system so the main
 * code doesn't have to work this out.
 *
 * Copyright (c) 2021, University of New Hampshire, Center for Coastal and Ocean Mapping.
 *
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
 * THE SOFTWARE IS PROVIDED "AS IS", WITHOUT WARRANTY OF ANY KIND, EXPRESS OR
 * IMPLIED, INCLUDING BUT NOT LIMITED TO THE WARRANTIES OF MERCHANTABILITY, FITNESS
 * FOR A PARTICULAR PURPOSE AND NONINFRINGEMENT. IN NO EVENT SHALL THE AUTHORS
 * OR COPYRIGHT HOLDERS BE LIABLE FOR ANY CLAIM, DAMAGES OR OTHER LIABILITY,
 * WHETHER IN AN ACTION OF CONTRACT, TORT OR OTHERWISE, ARISING FROM, OUT OF
 * OR IN CONNECTION WITH THE SOFTWARE OR THE USE OR OTHER DEALINGS IN THE SOFTWARE.
 */

#define LOG_LOCAL_LEVEL ESP_LOG_VERBOSE
#include "esp_log.h"

#include "MemController.h"
#include "FS.h"
#include "SD.h"
#include "SPI.h"
#include "SD_MMC.h"
#include "Configuration.h"
#include "eMMCController.h"

namespace mem {

const uint8_t default_cs_pin = 5;   ///< Pin used to control selection of the SD card when in SPI mode

/// \class SPIController
/// \brief Specialisation of the MemController interface for SPI bus
///
/// This assumes that the SPI bus used is the VSPI default, which is what's used on NEMO-30.  This means
/// that no specialist configuration is required to bring up the system.

class SPIController : public MemController {
public:
    /// \brief Default constructor
    ///
    /// This stores the pin to use for Chip Select (CS*) when accessing the SD card, but otherwise
    /// does not access the card.
    ///
    /// \param cs_pin   GPIO pin number to use for chip select when accessing the SPI card

    SPIController(uint8_t cs_pin = default_cs_pin)
    : m_csPin(cs_pin)
    {
    }

    /// \brief Default destructor

    ~SPIController(void)
    {
    }

private:
    uint8_t    m_csPin; ///< GPIO pin number to use for chip select

    /// \brief Start up the SPI interface to get to SD card online
    ///
    /// This initialises the SPI interface, using the CS pin specified at construction, allowing for
    /// a few repetitions (which are sometimes required, according to Dr. Google) for the chip to
    /// reset and restart.
    ///
    /// \return True if the interface started, otherwise False

    bool start_interface(void)
    {
        // By default, the interface chosen for SPI is the ESP32's VSPI, which is what NEMO-30 uses,
        // so we don't need to configure the SPI interface to make this work.

        bool rc = false;
        int rep = 0;
        while (rep < 10 && !rc) {
            Serial.printf("DBG: repeat %d for SD start ...\n", rep);
            rc = SD.begin(m_csPin);
            ++rep;
        }
        return rc;
    }

    /// \brief Shut down SPI interface.
    void stop_interface(void)
    {
        SD.end();
    }

    /// \brief Return a reference to the SPI interface being used.
    fs::FS& get_interface(void)
    {
        return SD;
    }
};

/// \class MMCController
/// \brief Specialisation of the MemController interface for SD/MMC modules
///
/// This provides an interface to configure and start up an SD/MMC module, either an
/// SD card configured on the SD/MMC interface (higher speed, 4-bit), or an eMMC module,
/// if available (only supported on NEMO30).

class MMCController : public MemController {
public:
    /// \brief Default constructor
    MMCController(void)
    {
#ifdef BUILD_NEMO30
        m_eMMCController = new nemo30::eMMCController();
        m_eMMCController->setModuleStatus(true); // Enable CMD line to module
        m_eMMCController->resetModule();
#endif
    }

    /// \brief Default destructor
    ~MMCController(void)
    {
#ifdef BUILD_NEMO30
        delete m_eMMCController;
#endif
    }

private:
#ifdef BUILD_NEMO30
    nemo30::eMMCController  *m_eMMCController;  ///< Pointer to the eMMC module's hardware interface
#endif

    /// \brief Start up the SD/MMC interface
    ///
    /// This starts the interface, bringing the storage online
    ///
    /// \return True if the module initialised, otherwise False

    bool start_interface(void)
    {
        return SD_MMC.begin();
    }

    /// \brief Stop the SD/MMC interface
    ///
    /// This should stop the interface and idle the storage, but since the interface controller is
    /// always allocated, this may not recover memory.

    void stop_interface(void)
    {
        SD_MMC.end();
    }

    /// \brief Return a reference to the interface in use.
    fs::FS& get_interface(void)
    {
        return SD_MMC;
    }
};

/// All WIBL-based loggers have to provide some large-scale storage for the logged data, but the particular
/// interface on which that storage is provided can change.  This provides a mechanism to abstact away the
/// details of the interfacing by providing a uniform MemController pointer to use for control.
///
/// \return Pointer to the appropriate MemController sub-class to use for the current hardware.

MemController *MemControllerFactory::Create(void)
{
    bool use_sdio;
    MemController *rc = nullptr;

    if (!logger::LoggerConfig.GetConfigBinary(logger::Config::ConfigParam::CONFIG_SDMMC_B, use_sdio)) {
#ifdef PROTOTYPE_LOGGER
        Serial.println("ERR: prototype logger, setting VSPI SD interface.");
        use_sdio = false;
#else
        Serial.println("ERR: memory module interface not recognised!  Using SDIO.");
        use_sdio = true;
#endif
    }
    use_sdio = true;
    if (use_sdio) {
        Serial.println("Starting SD/MMC interface.");
        rc = new MMCController();
    } else {
        Serial.println("Starting SPI interface.");
        rc = new SPIController();
    }
    return rc;
}

}

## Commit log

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2019-11-25 Added Eagle EDA design files for ESP32-based hardware implementation.
    [SB2030_Logger_ESP32.brd, SB2030_Logger_ESP32.sch]
2019-12-02 Updates to hardware prototype design to support RS422 input, and added separate RS422 for Arduino Due for testing purposes.
    [Due_RS422_Transceiver.sch, SB2030_Logger_ESP32.brd, SB2030_Logger_ESP32.sch]
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2019-12-04 Added PCB layout for Arduino Due RS422 transceiver board components.
    [Due_RS422_Transceiver.brd]
2019-12-10 Small bug fixes for debugging only on demand, with interface from the outside to turn on/off.
    [N0183Logger.cpp, SerialCommand.cpp]
2019-12-10 Update to ESP32-based hardware to accommodate NMEA0183 input pins that don't cause boot problems (GPIO12 is used to set Flash voltage on boot, so having an active data stream attached causes all sort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
    [SB2030_Logger_ESP32.brd, SB2030_Logger_ESP32.sch]
2019-12-12 Updated schematic for ESP32, and source code, to reflect new choice of UART receiver pins.
    [Arduino_NMEA_TestBoard.brd, Arduino_NMEA_TestBoard.sch, SB2030_Logger_ESP32.brd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]
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2019-12-15 Bug fixes for serialising N2K GNSS data, and parsing at the other end.
    [N2kLogger.cpp]
2020-01-23 Added updates for reference hardware prototype, and prototype PCB for development boards.
    [ESP32-DevBoard-Prototype.brd, ESP32-DevBoard-Prototype.sch, SB2030_Logger_ESP32.brd]
2020-02-04 Updated board for ESP32 dev-board hardware to remove unnecessary traces.
    [ESP32-DevBoard-Prototype.brd]
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2020-02-05 Update to trace layout on Arduino Due development board to smooth out some kinks.
    [Arduino_NMEA_TestBoard.brd]
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2020-04-02 Update to NMEA0183 simulator GPGGA generation, and added post-processing timestamping outline; small fix for documentation in logger firmware.
    [LoggerFirmware.ino]
2020-06-24 Bug fixes for WiFi interface version of the logger - Fixed numpty bug in WiFi connection testing that was infinite recursing itself ... oops. - Added check for a WiFi server existing before trying to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
    [LogManager.cpp, LoggerFirmware.ino, ParamStore.cpp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]
2020-06-24 Fixed issue 10 (inefficient use of space in Bluefruit NVM for parameter storage).
    [ParamStore.cpp]
2020-06-26 Fixed output for reporting WiFi commands so that it behaves the same as other command streams.
    [SerialCommand.cpp]
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2020-07-01 Added facility to flash an LED for a data event to both hardware simulator and firmware. - Updated StatusLED.cpp to provide physical interface, and separated out the third LED on the development boar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
    [LogManager.cpp, LogManager.h, LoggerFirmware.ino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]
2020-07-02 Added code to firmware to provide file size as a 32-bit unsigned before transfer, so that the receiver knows how much data to expect before swapping back to ASCII interpretation of the return codes.
    [LogManager.cpp]
2020-07-03 Updated serial command buffering to avoid stalling run-loop, and truncating commands if you pause. - Added IncrementalBuffer.h to provide base class to assemble a string - Updated N0183Logger.cpp to 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
    [LogManager.cpp, LogManager.h, LoggerFirmware.ino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]
2020-07-04 Updates to provide interface to invert the RX pin logic if the input is round the wrong way, and to do so automatically if it looks likely. - Added manual command "invert on|off channel" to the Seria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
    [N0183Logger.cpp, SerialCommand.cpp]
2020-07-08 Updates to PCB coppers for the production board design (to work out some inexplicable air wires).
    [SB2030_Logger_ESP32.brd, SB2030_Logger_ESP32.sch]
2020-07-09 Updated logging on N0183 to make sure that a console message is logger if the code inverts the input channel to deal with polarity on the incoming channel(s).
    [LogManager.cpp, N0183Logger.cpp]
2020-07-09 Added MIT license statements to all active files, and removed a couple of older files that are no longer required.
    [StatusLED.cpp, StatusLED.h]
2020-07-13 Simple prototype for a super-capacitor temporary power supply to allow for orderly shutdown.
    [supercap-backup.sch]
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2021-02-12 Updated NMEA0183 logger to use appropriate pins for NEMO-30 so that (unused) UART TX pins won't conflict with anything.
    [N0183Logger.cpp]
2021-02-12 Bug-fix in WiFi adapter shutdown to avoid kernel panic.
    [WiFiAdapter.cpp]
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2021-02-14 Bug fixes in LED controller.
    [StatusLED.cpp]
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2021-02-16 Fixed bug in StatusLED that was preventing blue channel from working.
    [StatusLED.cpp]
2021-02-26 Added configuration object implementation.
    [Configuration.h]
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2021-03-05 Fixed bug that would stop you setting the RX invert state for the last NMEA0183 channel.
    [N0183Logger.cpp]
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2021-03-15 Major updates to SMD board design (added motion sensor and power management), with re-layout for production. Added Gerbers, BOM, and CPL for JLCPCB production. Added library for MPU6050 IMU. Added CC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
    [SB2030_Logger_ESP32.brd, SB2030_Logger_ESP32.sch, SB2030_Logger_ESP32_BOM.csv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]
2021-03-16 Re-routed demonstration board to ensure that the power distribution is better.
    [SB2030_Logger_ESP32.brd]
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2021-03-17 Updates to library specifications for devices, and schematic/board to match in order to give better match to actual components; V2.3 of demonstration board.
    [SB2030_Logger_ESP32.brd, SB2030_Logger_ESP32.sch]
2021-03-17 Modifications to PCB layout to improve ground planes, and to attempt to fix centroid problems for ESP32-WROOM-32E
    [SB2030_Logger_2.3.0_BOM.csv, SB2030_Logger_ESP32.brd, SB2030_Logger_ESP32.sch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]
2021-03-18 Modifications to allow for separate compilation for OpenHardware or NEMO30 (-DBUILD_NEMO30 in platformio.ini) versions of the logger: - Moved supply voltage monitor (power-out check) to logger namesp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
    [LogManager.cpp, MemController.cpp, SerialCommand.cpp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]
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2021-04-16 Debugging fixes for NEMO-30 and WIBL support - Added builds for NEMO-30 separate from prototype loggers and WIBL - Added pass-back for value read from ADC for power monitoring - Pushed CAN traffic to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
    [SB2030_Logger_ESP32.brd, SB2030_Logger_ESP32.sch]
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2021-07-04 Updates to design for WIBL, board and schematic, to match new SMPS integration, and other small fixes for layout of power input, and super-capacitor charging circuit.
    [SB2030_Logger_ESP32.brd, SB2030_Logger_ESP32.sch]
2021-07-26 Updates to SerialCommand to allow for echo of characters to the serial line (so you can see what you're typing) and to allow for backspace to correct mistakes in typing.
    [SerialCommand.cpp]
2021-08-04 Patched around potential divide by zero error in NMEA0183 false-start detection (i.e., auto-inverse).
    [N0183Logger.cpp]
2021-08-12 Modifications to file transfer code in an attempt to speed up transfer, and debug transfer glitches.
    [LogManager.cpp, SerialCommand.cpp, WiFiAdapter.cpp]
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2021-08-26 Fixed bug in IMU logger where the settings were ignored because they were done before the core initialisation. Added check to see if the new data is the same as the last (which can happen because we'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
    [IMULogger.cpp]
2021-08-29 Added configuration parameters and code to allow the baud rate for NMEA0183 to be set (rather than assuming 4800), and to choose whether to boot on BLE or WiFi.
    [Configuration.h]
2021-09-01 Added code to bridge UDP broadcast packets with NMEA strings on WiFi to one of the NMEA0183 transmitters, if required, with associated changes to the SerialCommand and Configuration elements.
    [Configuration.h]
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2021-09-08 Added functionality to report the metadata string, if available, and to avoid having to write a terminator into the metadata file.
    [SerialCommand.cpp]
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2021-09-11 Bug fix in NMEA0183 filtering to ensure that no filter IDs mean that everything is accepted (the default case).
    [N0183Logger.cpp]
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2021-09-15 Bug fixes for new features: 1. Made it possible to change the size of the IncBuffer object (IncrementalBuffer.h) at runtime to accommodate longer commands (e.g., for metadata strings). 2. Used above 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
    [NVMFile.cpp, SerialCommand.cpp]
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2021-11-16 Updates to DCDB file loader in AWS Lambda - Abstraction out of AWS specifics to DataSource/CloudController. - Canonical handling of configuration JSON through the Config sub-routine. - Updated code t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
2021-11-19 Multiple updates to AWS processing chain: - Added a handler for lineage data being added to the JSON metadata for files; code in lineage.py provides support for adding information to this. - Upgraded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
2021-11-23 Updates and bug-fixes to AWS Lambdas: - Improved reporting of details of processing when the "verbose" mode is turned on in the code. - Fixed bug in Timestamping.py which caused exceptions due to a v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
2021-12-15 Fixed bug in firmware serialiser - Serialiser buffer re-sizing was causing heap errors if the item being added was more than twice the size of the current buffer. Fixed. - Added specific sizing for J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
    [LogManager.cpp, NVMFile.cpp]
2022-03-08 Fixed typo in packet identification in LoggerFile.py (caused pressure packets not to be recognised).
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2022-03-21 Fixed I2C register address auto-increment problem on LSM6 device.
    [IMULogger.cpp]
2022-03-21 Added local scale factors for IMU readings to avoid having to re-compute each time, and set up for actual values in IMU parameter configuration.
    [IMULogger.cpp]
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2022-04-05 Initial commit of new branch, corrected SDA and SCL crossed connections and rerouted INt1 more appropriately
    [SB2030_Logger_ESP32_bkp.brd, SB2030_Logger_ESP32_bkp.sch]
2022-04-22 Please enter the commit message for your changes. Lines starting
    [SB2030_Logger_ESP32.brd, SB2030_Logger_ESP32.sch]
2022-04-23 Fixed labelling on schematic for INT1 from IMU, and cleaned up some notation; fixed routing and airwires on board so that DRC passes.
    [SB2030_Logger_ESP32.brd, SB2030_Logger_ESP32.sch]
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2022-07-12 Fixed bug (hang-over from a previous version of the API) in timestamp_data.py. This allows the code to work with the current version of AWS/Processing/Timestamping.py.
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2023-01-28 Updated version information on PCB silk-screen (2.4.0), cleaned up hardware projects directory, renamed main schematic and board to reflect WIBL naming.
    [Arduino_NMEA_TestBoard.brd, Arduino_NMEA_TestBoard.sch, Due_RS422_Transceiver.brd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]
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2023-02-21 Added parameter to configure web server interface use.
    [Configuration.h]
2023-02-21 Added parameters and supporting code to control the webserver configuration interface.
    [Configuration.h]
2023-02-21 Removed redundant BLE controller and supporting configuration variables.
    [Configuration.h]
2023-02-22 First cut at a web-server based configuration system and command interface for the logger firmware.
    [Configuration.h]
2023-02-22 Fixed up web-server implementation so that it is called in run-loop and accumulates messages to return when required.
    [SerialCommand.cpp, WiFiAdapter.cpp]
2023-02-24 Added JSON-format setup reporting and configuration so that the entire setup for the logger can be done in one pass.
    [Configuration.h]
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2023-02-24 Added "status" command to generate information on the current state of the logger (WiFi mode, count of files, file sizes, etc.). Fixed bug in filename enumeration.
    [LogManager.cpp, SerialCommand.cpp]
2023-02-24 Preliminary implementation of a WiFi station "failsafe" mode so that a bad station configuration (or missing network) doesn't stop the logger, and the logger eventually reverts to AP mode.
    [Configuration.h]
2023-02-25 Added debugging messages to the connection state machine for WiFi in station mode to visualise the process (off by default) and added NV variable to store status of WiFi at boot so that you can tell 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
    [Configuration.h]
2023-02-26 Fixed bug in enumeration of files that was causing the filename to be misinterpreted (and therefore giving poor data on "sizes").
    [LogManager.cpp]
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2023-03-03 Added timeouts to webserver-based GUI to avoid hangs when the logger isn't available, and added GUI to set/reset/load/save algorithm definitions; adjusted firmware handling to facilitate this.
    [NVMFile.cpp, SerialCommand.cpp]
2023-03-04 Added webserver-based GUI functionality to query/set logger, and load/save NMEA0183 sentence filters. Bug-fix for algorithm specification to avoid problems where there are none in the logger on query.
2023-03-04 Refactored webserver-based firmware configuration code so that it can be used to write setup config to log files, including provision to avoid writing passwords to the log file(!). Added a new packet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
    [Configuration.h]
2023-03-05 Updates to "default" configuration storage and management: 1. Added facility for "lab defaults" configuration string (in JSON format) to be added to the logger, so that the user can reset to a known-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
    [Configuration.h]
2023-03-06 Cleaned up old manufacturing files that shouldn't be in the repository.
    [SB2030_Logger_2.3.0_BOM.csv, SB2030_Logger_ESP32_BOM.csv, SB2030_Logger_ESP32_PnP.csv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]
2023-03-06 Update to platform patch code since the UART invert code has been added to the default. The WebServer.cpp code is required to remove a "fix" for Chrome that causes responses to be terminated after th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
2023-03-07 Bug fix for "erase all" command in firmware; adjusted serialisation in LogManger.cpp to avoid writing a JSON-Metadata and SensorScales packet if there's nothing to write.
    [LogManager.cpp, NVMFile.cpp]
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2023-03-21 Bug fix in log conversion C++ (update to v 1.3 serialisation version, adds IMU version information), DCDB upload, and name/uniqueid clarification in Python file parser.
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2023-08-17 logger: added stable configuration to logger firmware so that the logger will boot with a known config if it hasn't been started previously. This is a static string in Configuration.cpp, generated wi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
    [Configuration.h]
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2023-11-27 (Firmware): Added code to inline and flatten the website to avoid multi-reference GETs from the (single threaded!) web server. Also update to latest ESP32 IDF.
    [WiFiAdapter.cpp]
2023-11-29 (Firmware): WIP: Support for consistent JSON output from logger commands when on WiFI.
    [Configuration.h]
2023-12-01 (Firmware): Major updates to the firmware command processor to ensure that JSON is generated on output consistently for WiFi commands, allowing the internal website to function much more efficiently.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
    [NVMFile.cpp, SerialCommand.cpp, main.cpp]
2023-12-01 (Firmware): cleanup of version handling, and provided a mechanism for the firmware to have an "overall" version (i.e., code for the assembly of components).
    [Configuration.h]
2023-12-01 (Firmware): Functionality for an upload handshake token to be stored in logger, and facilities to set it in website and DesktopUI. Update to website and DesktopUI for firmware version display. Update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
    [Configuration.h]
2023-12-04 (Firmware): added facility to rotate the console log at a fixed size (by default 100kB) and keep a certain number of them around (by default 3) so that the maximum size used by the console log is lim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
    [LogManager.cpp, LogManager.h, N0183Logger.cpp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]
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2023-12-11 (Firmware): Bug-fix to allow the state of the algorithm request store and NMEA0183 filters to be reported correctly on WiFi.
    [NVMFile.cpp, SerialCommand.cpp]
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2023-12-12 (Firmware): Initial updates to support auto-upload from the logger (if the network has internet connection).
    [Configuration.h]
2023-12-13 wibl-python: data preview: Filter out values less than 0 from soundings when rasterizing for visualization; Flip color map to use warm colors for shallow cool colors for deep
2023-12-14 (Firmware): multiple updates to flesh out auto-upload code to first approximation (pre-test); added very simple server to catch requests, enabling local testing.
    [Configuration.h]
2023-12-22 (Firmware): Updates to memory handling for JsonDocuments, switch to LittleFS for better performance, to avoid a second memory controller starting when the LogManager is instantiated, to add upload co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
    [AutoUpload.cpp, LogManager.cpp, LogManager.h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]
2023-12-23 (Firmware): Bug-fixes to make sure that parameter files and NVM files exist before we attempt to open (by creating an empty file). Added debug configuration to allow the exception decoder to be used 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
    [NVMFile.cpp, ParamStore.cpp]
2024-01-03 (Firmware): updates and bug fixes for auto-upload.
    [AutoUpload.cpp, NVMFile.cpp, SerialCommand.cpp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]
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2024-01-03 (Firmware): updates and bug-fixes for auto-uploading, including provision of API token if available, and ability to count files without enumerating all of the file ID numbers. Also bug-fix for having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
    [AutoUpload.cpp, LogManager.cpp, LogManager.h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]
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2024-01-17 (Firmware): WIP: Adding HTTPS and BasicAuthentication mechanisms for auto-upload.
    [Configuration.h, partition_4MB.csv]
2024-01-18 (Firmware): bug-fixes and corrections for TLS and BasicAuth on auto-upload service.
    [AutoUpload.cpp]
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

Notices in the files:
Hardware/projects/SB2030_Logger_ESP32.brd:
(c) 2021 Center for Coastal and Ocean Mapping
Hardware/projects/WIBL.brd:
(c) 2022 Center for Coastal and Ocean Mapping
